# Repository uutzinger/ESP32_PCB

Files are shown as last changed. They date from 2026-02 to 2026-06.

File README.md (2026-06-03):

# ESP32 PCBs

Designed with KiCad by Urs Utzinger, February - June 2026.

- Full size battery operated ESP32-S3-Mini
- Minimial size ESP32-S3.
- Minimal size ESP32-C6, low power.

Based on S3/C6-mini modules.

<table style="width:100%; table-layout:fixed;">
  <tr>
    <td valign="bottom" style="width:33.3%; text-align:center;">
      <a href="./EPS32_S3_1.md">
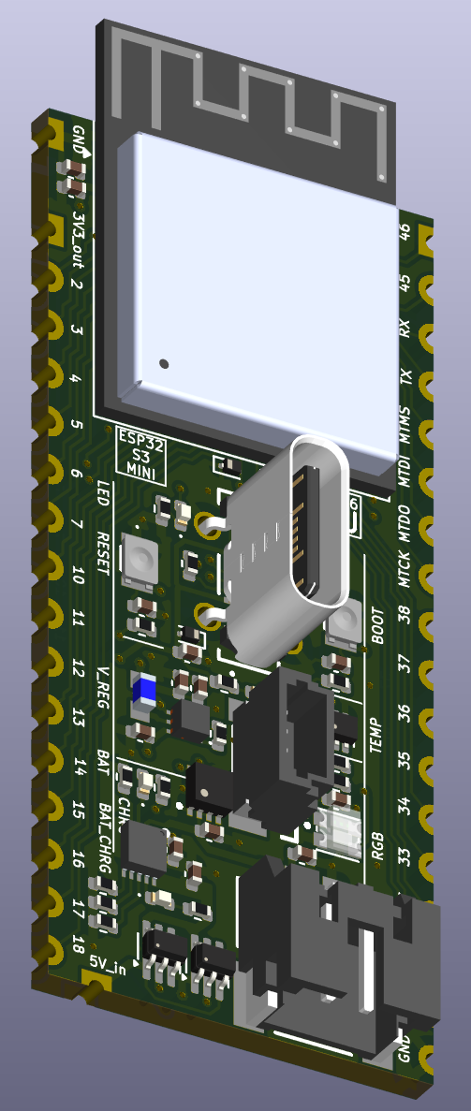
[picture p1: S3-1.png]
ESP32-S3-MINI-1
        
      </a>
      <br>
      <b>ESP32-S3-MINI-1</b>
      <ul style="text-align:left; margin:8px auto; max-width:90%; list-style:none; padding-left:0;">
        <li>📡 Antenna</li>
        <li>🔋 Battery management</li>
        <li>📊 Battery gauge</li>
        <li>⚡ Dual supply power (ext 5V or USB 5V) </li>
        <li>⇄ USB-C</li>
        <li>🔗 QWIIC</li>
        <li>🌈 RGB LED</li>
        <li>🌡 Temperature sensor</li>
        <li>🔘 Bootmode, Reset buttons</li>
      </ul>
    </td>
    <td valign="top" style="width:33.3%; text-align:center;">
      <a href="./EPS32_S3_1U.md">
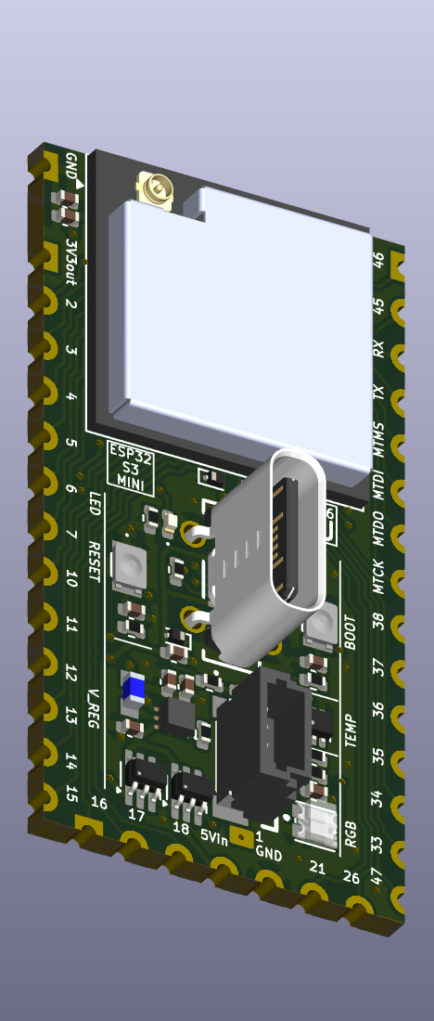
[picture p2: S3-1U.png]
ESP32-S3-MINI-1U
        
      </a>
      <br>
      <b>ESP32-S3-MINI-1U</b>
      <ul style="text-align:left; margin:8px auto; max-width:90%; list-style:none; padding-left:0;">
        <li>⚡ Dual supply power (external 5V or USB 5V)</li>
        <li>⇄ USB-C</li>
        <li>🔗 QWIIC</li>
        <li>🌈 RGB LED</li>
        <li>🌡 Temperature sensor</li>
        <li>🔘 Bootmode, Reset buttons</li>
      </ul>
    </td>
    <td valign="top" style="width:33.3%; text-align:center;">
      <a href="./EPS32_C6_1.md">
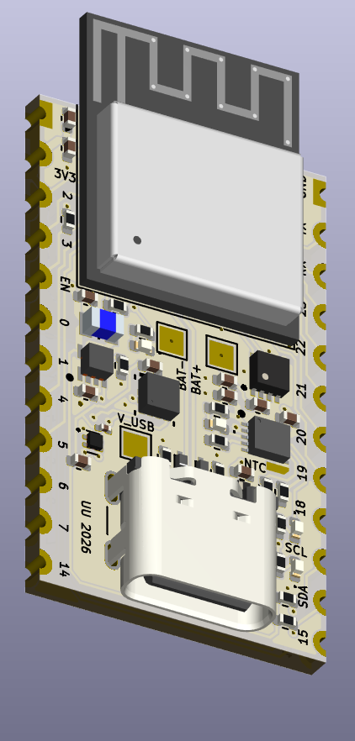
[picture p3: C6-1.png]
ESP32-C6-MINI-1
        
      </a>
      <br>
      <b>ESP32-C6-MINI-1</b>
      <ul style="text-align:left; margin:8px auto; max-width:90%; list-style:none; padding-left:0;">
        <li>📡 Antenna</li>
        <li>🔋 Battery management</li>
        <li>📊 Battery gauge</li>
        <li>⇄ USB-C</li>
        <li>🌡 Temperature sensor</li>
        <li>🫨 Acceleromter</li>
        <li>no Buttons
      </ul>
    </td>
  </tr>
</table>

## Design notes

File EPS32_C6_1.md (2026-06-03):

## ESP32-C6-MINI-1

Size 17.8 x 35.75  mm

- ESP32-C6-MINI-1 module ,main [MCU](ESP32-C6/assets/esp32-c6-mini-1_mini-1u_datasheet_en.pdf) $I_q = 8 \mu A$ 
- BQ25185DLHR [Battery Management / Charger](ESP32-C6/assets/bq25185.pdf) $I_q = 4 \mu A$ (might want to replace with BQ25638 sometime in future)
- TPS62840DLRC 3.3V step-down [Voltage Regulator](ESP32-C6/assets/tps62840.pdf) $I_q = 60nA $
- MAX17048 LiPo [fuel gauge](ESP32-C6/assets/max17048-max17049.pdf) $I_q = 0.5 \mu A$ (would no longer be need if BQ25638 is used)
- TMP110D digital temperature sensor, [TMP110D temperature sensor](ESP32-C6/assets/tmp110.pdf) $I_q = 0.15 \mu A$
- LIS2DW12 [acceleromter](ESP32-C6/assets/lis2dw12.pdf) $I_q = 50 nA$hundred
- USB4105 (USB-C receptacle) (datasheet not added yet) + ESD protection (ESD9B5.0ST5G)
- Castellated edge connectors

### Bill of Materials
- [BOM ESP32 C6 MINI 1](ESP32-C6/BOM.xlsx)

### Design Materials
<table>
  <tr>
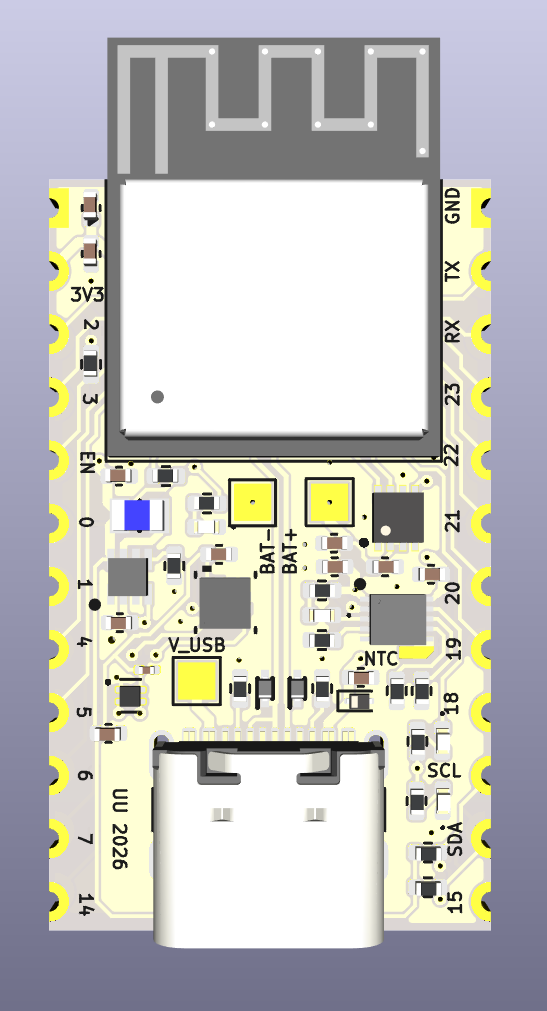
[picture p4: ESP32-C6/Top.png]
Front
    <td></td>
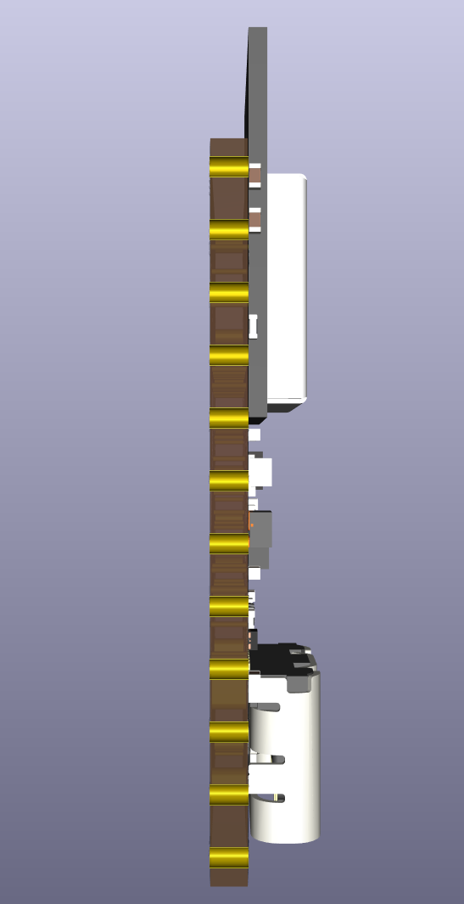
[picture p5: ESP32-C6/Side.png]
    <td></td>
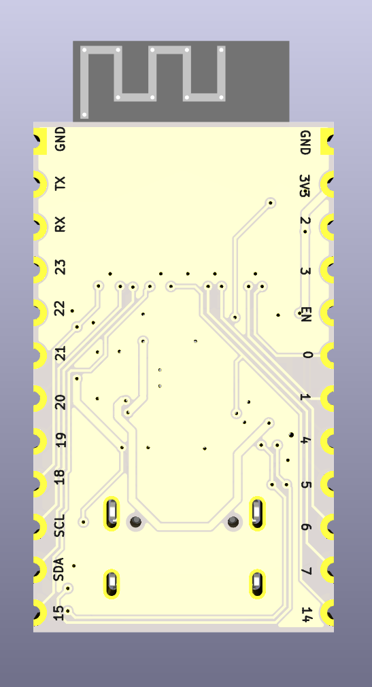
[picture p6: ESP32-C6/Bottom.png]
    <td></td>
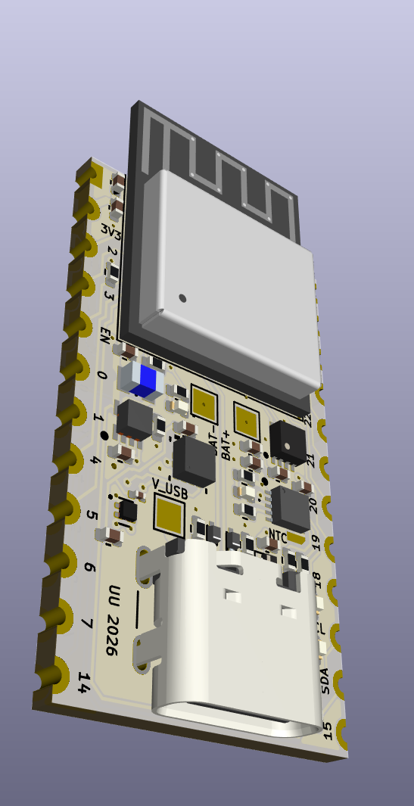
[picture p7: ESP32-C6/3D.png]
    <td></td>    
  </tr>
</table>

<a href="./ESP32-C6/Schematic.svg">
  Schematic
</a>

<a href="./ESP32-C6/PCB.svg">
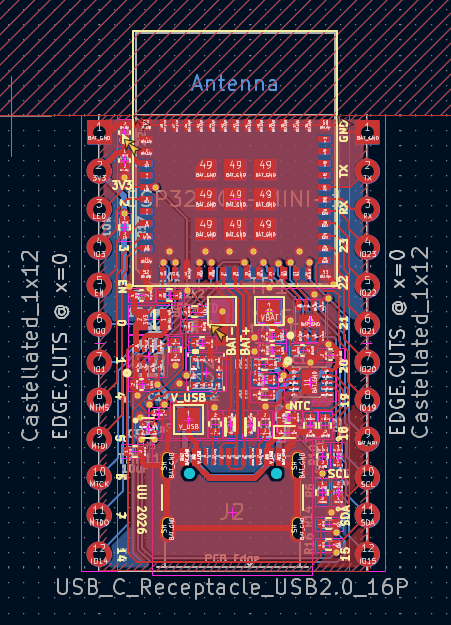
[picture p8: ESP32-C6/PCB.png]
PCB
  
</a>

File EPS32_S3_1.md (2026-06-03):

## ESP32-S3-MINI-1

Size 20.32 x 50.82 mm

- ESP32-S3-MINI-1 module ,main [MCU](ESP32_S3_MINI_1/assets/esp32-s3-mini-1_mini-1u_datasheet_en.pdf)
- BQ25185DLHR [Battery Management / Charger](ESP32_S3_MINI_1/assets/bq25185.pdf)
- TPS6282533DMQR 3.3V step-down [Voltage Regulator](ESP32_S3_MINI_1/assets/tps62825.pdf)
- MAX17048 LiPo [fuel gauge](ESP32_S3_MINI_1/assets/max17048-max17049.pdf)
- TMP102 digital temperature sensor, [TMP102 temperature sensor](ESP32_S3_MINI_1/assets/tmp102.pdf)
- USB4120-03-C (USB-C receptacle)[ESP32_S3_MINI_1/USB4120-03-C USB-C receptacle](ESP32_S3_MINI_1/assets/usb4120-spec.pdf) + ESD protection (ESD9B5.0ST5G)
- WS2812B 2020 RGB LED [WS2812B 2020 RGB LED](ESP32_S3_MINI_1/assets/WS2812B-2020-Worldsemi.pdf), + discrete status LEDs (green/red), 
- Qwiic JST-SH 1.0mm 4-pin connector (I2C), [JST SH 1.0mm (Qwiic)](ESP32_S3_MINI_1/assets/eSH.pdf)
- JST 2.0mm 2-pin LiPo battery connector, [JST PH 2.0mm (LiPo)](ESP32_S3_MINI_1/assets/ePH.pdf)
- Power stage [TFM160808ALC-R47MTAA inductor](ESP32_S3_MINI_1/assets/inductor_commercial_power_tfm160808alc_en.pdf)
- Power switch and reverse polarity protection [LM66100](ESP32_S3_MINI_1/assets/lm66100.pdf)
- Tactile buttons (NANOT160AS) [Buttons](ESP32_S3_MINI_1/assets/nanot.pdf)
- Castellated edge connectors

### Bill of Materials
- [BOM ESP32_S3_MINI_1](ESP32_S3_MINI_1/BOM.xlsx)

### Design Materials
<table>
  <tr>
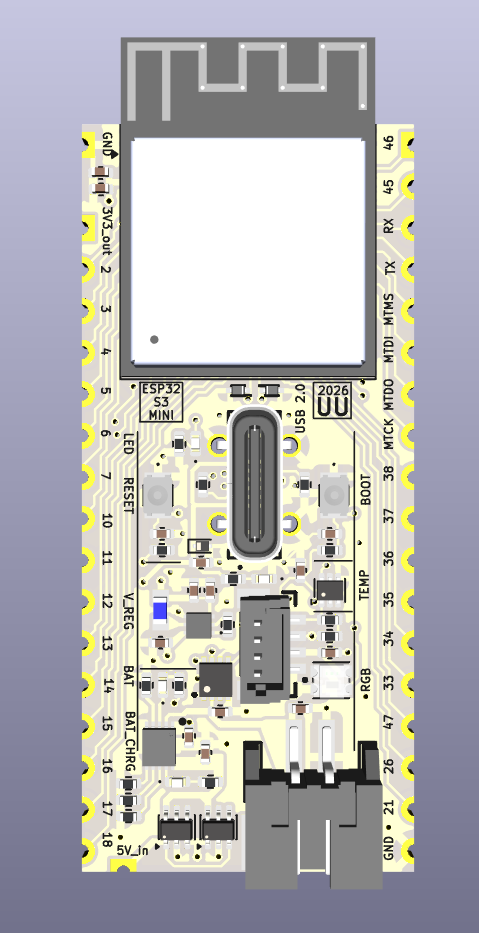
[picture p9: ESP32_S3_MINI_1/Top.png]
Front
    <td></td>
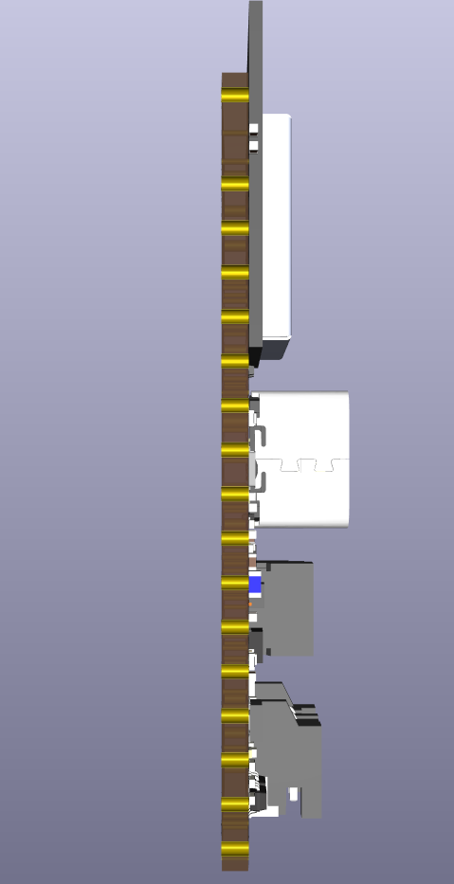
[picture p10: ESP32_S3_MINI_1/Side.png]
    <td></td>
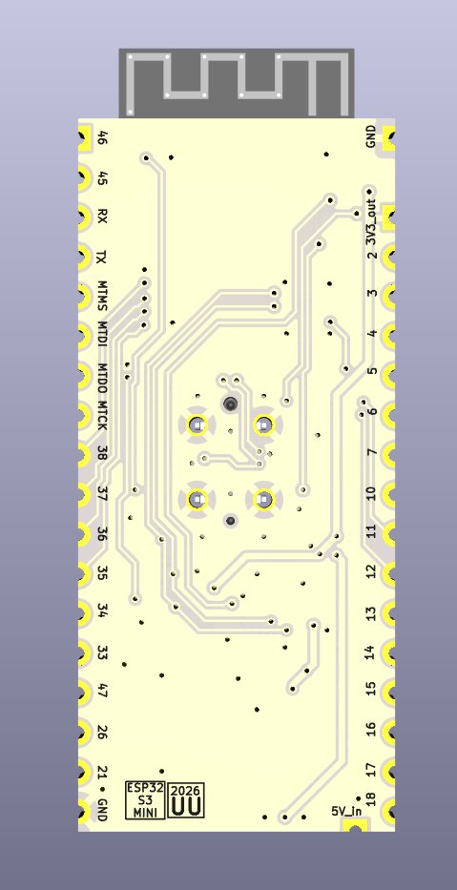
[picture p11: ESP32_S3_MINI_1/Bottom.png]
    <td></td>
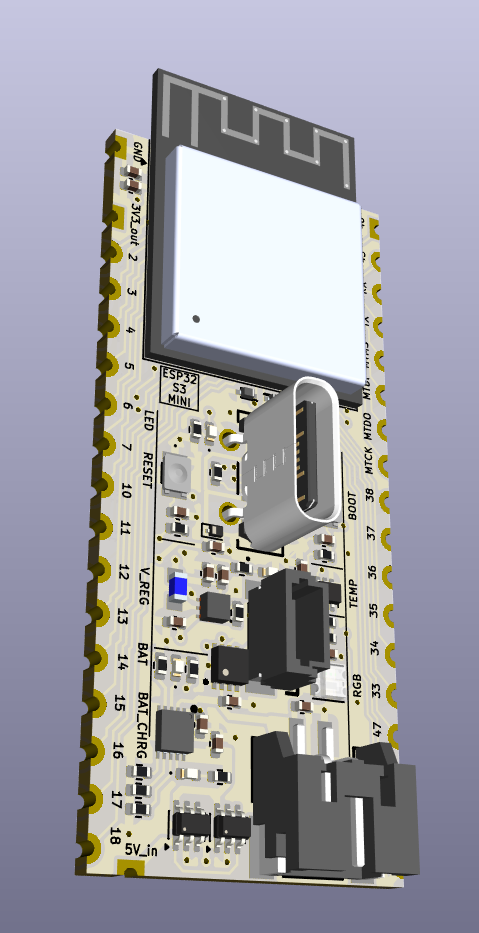
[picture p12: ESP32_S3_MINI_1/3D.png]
    <td></td>    
  </tr>
</table>

<a href="./ESP32_S3_MINI_1/Schematic.svg">
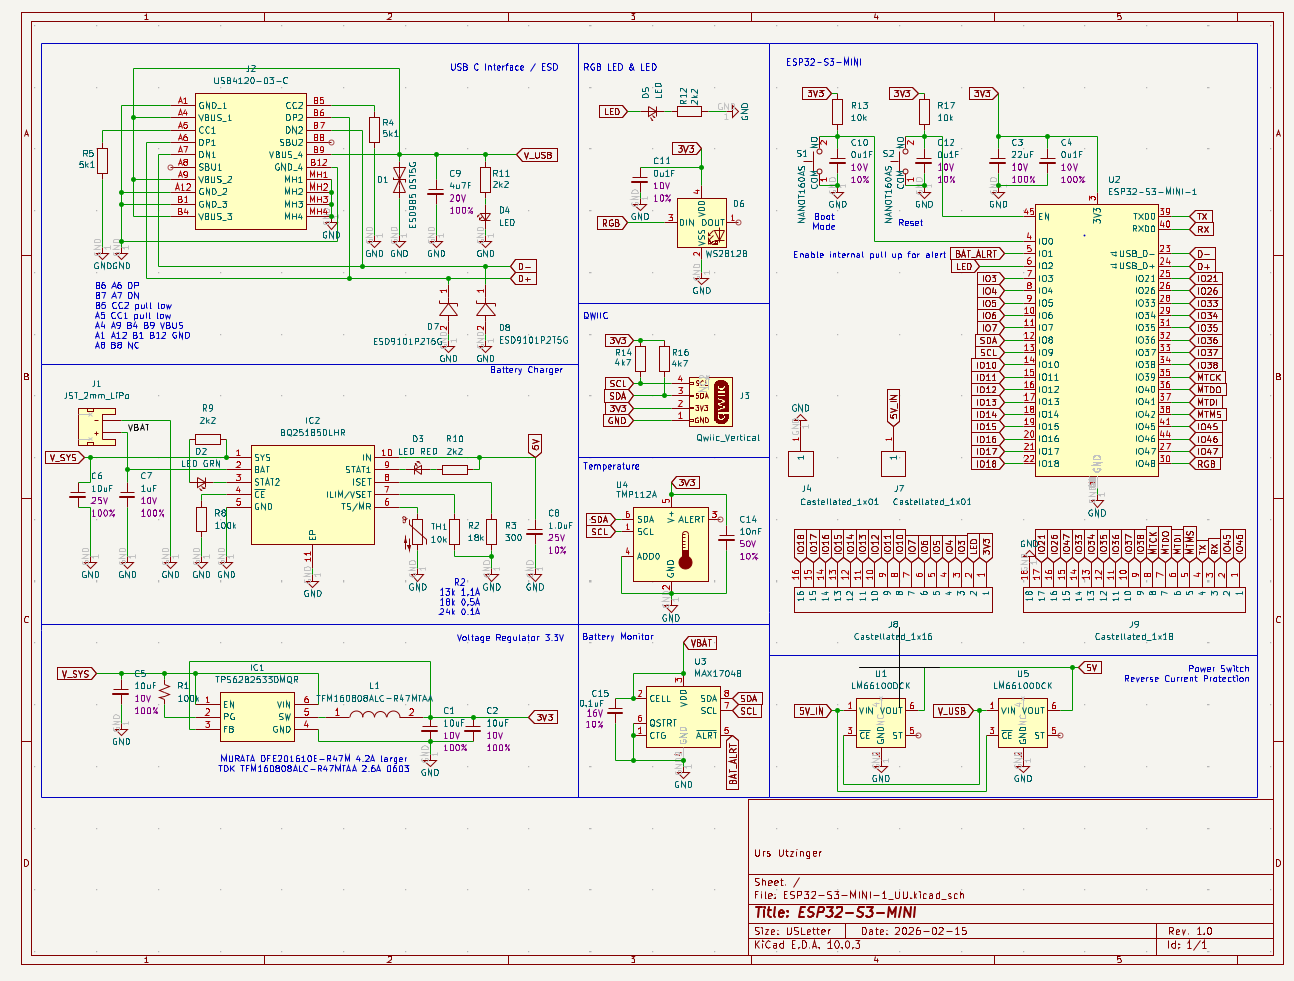
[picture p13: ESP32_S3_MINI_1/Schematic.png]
Schematic
  
</a>

<a href="./ESP32_S3_MINI_1/PCB.svg">
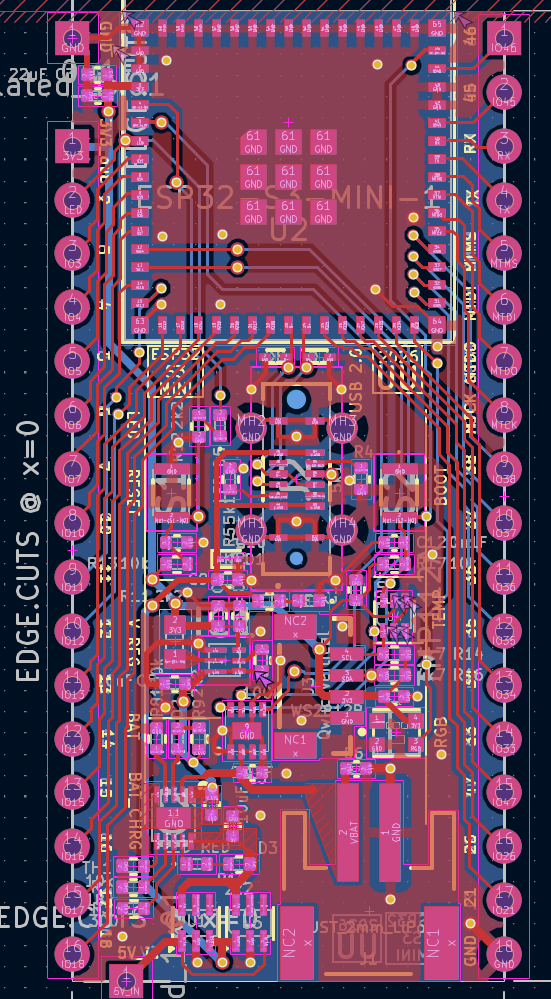
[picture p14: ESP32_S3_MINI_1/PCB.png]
PCB
  
</a>

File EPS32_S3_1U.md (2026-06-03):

## ESP32-S3-MINI-1U

Size 20.32 x 38.1 mm

- ESP32-S3-MINI-1U module ,main [MCU](ESP32_S3_MINI_1U/assets/esp32-s3-mini-1_mini-1u_datasheet_en.pdf)
- TPS6282533DMQR 3.3V step-down [Voltage Regulator](ESP32_S3_MINI_1U/assets/tps62825.pdf)
- TMP112 digital temperature sensor, [TMP112 temperature sensor](ESP32_S3_MINI_1U/assets/tmp112.pdf)
- USB4120-03-C (USB-C receptacle)[ESP32_S3_MINI_1/USB4120-03-C USB-C receptacle](ESP32_S3_MINI_1U/assets/usb4120-spec.pdf) + ESD protection (ESD9B5.0ST5G)
- WS2812B 2020 RGB LED [WS2812B 2020 RGB LED](ESP32_S3_MINI_1U/assets/WS2812B-2020-Worldsemi.pdf), + discrete status LEDs (green/red), 
- Qwiic JST-SH 1.0mm 4-pin connector (I2C), [JST SH 1.0mm (Qwiic)](ESP32_S3_MINI_1U/assets/eSH.pdf)
- Power stage [TFM160808ALC-R47MTAA inductor](ESP32_S3_MINI_1U/assets/inductor_commercial_power_tfm160808alc_en.pdf)
- Tactile buttons (NANOT160AS) [Buttons](ESP32_S3_MINI_1U/assets/nanot.pdf)
- Power switch and reverse polarity protection [LM66100](ESP32_S3_MINI_1U/assets/lm66100.pdf)
- Castellated edge connectors

### Bill of Materials
- [BOM ESP32_S3_MINI_1U](ESP32_S3_MINI_1U/BOM.xlsx)

### Design Materials
<table>
  <tr>
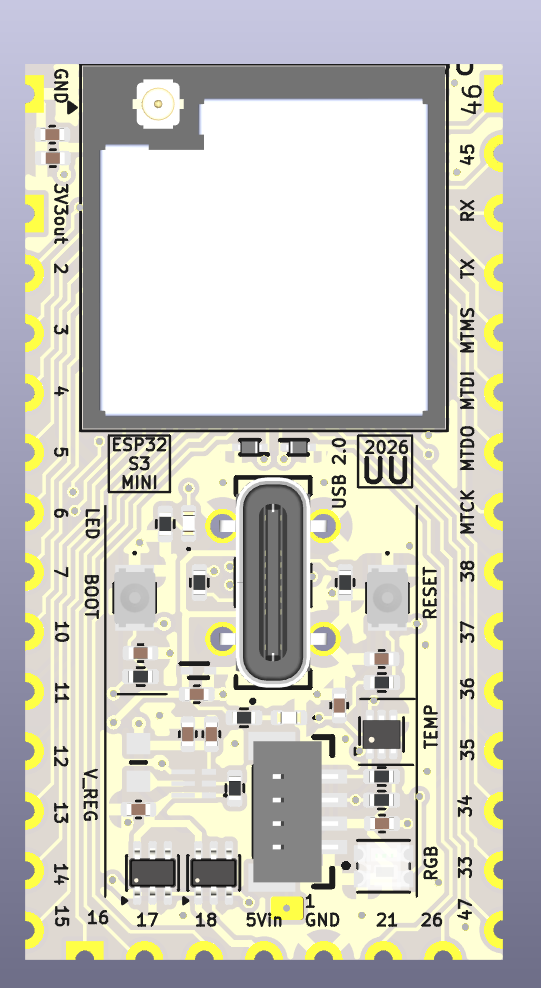
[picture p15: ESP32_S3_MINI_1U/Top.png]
Front
    <td></td>
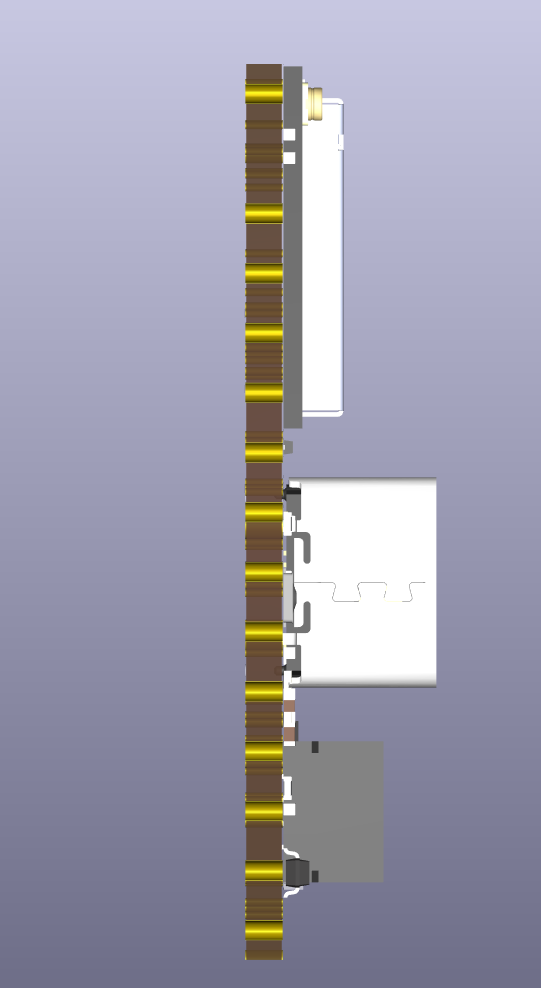
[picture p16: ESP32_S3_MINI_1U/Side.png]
    <td></td>
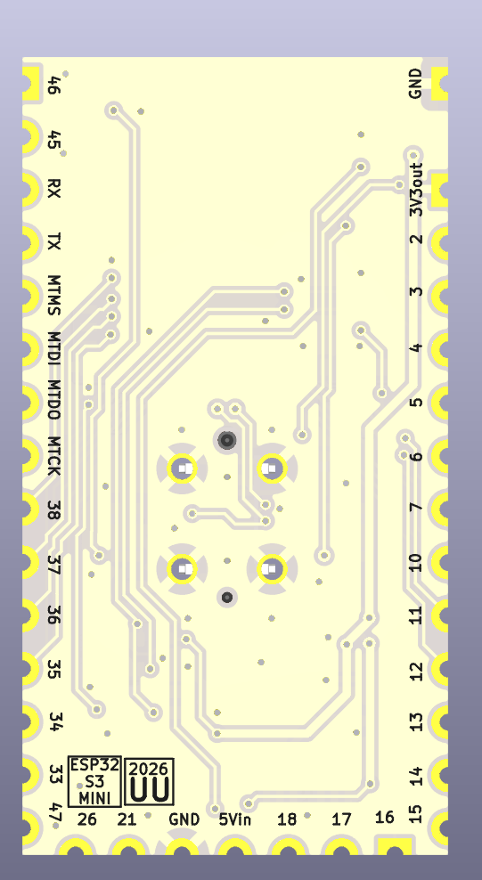
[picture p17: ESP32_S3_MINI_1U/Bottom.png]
    <td></td>
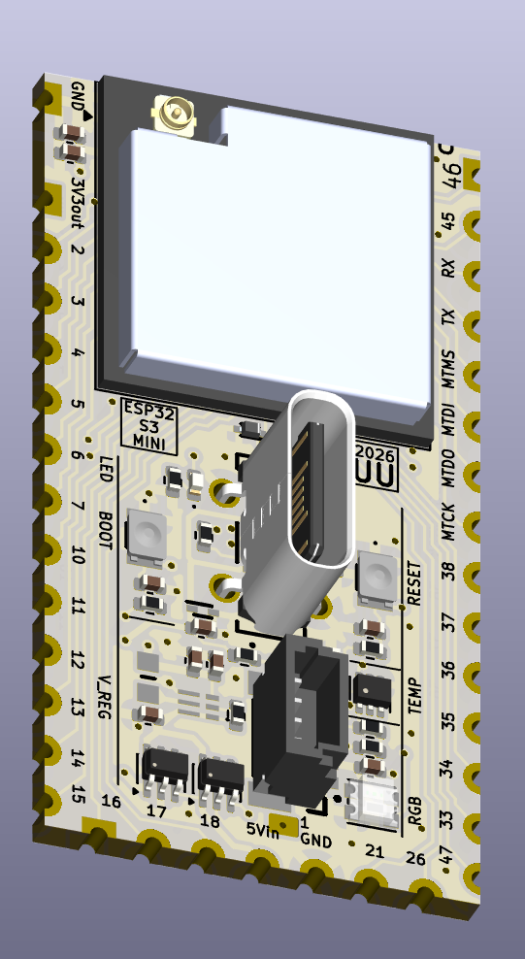
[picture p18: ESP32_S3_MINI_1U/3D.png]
    <td></td>    
  </tr>
</table>

<a href="./ESP32_S3_MINI_1U/ESP32-S3-MINI-1U_UU.svg">
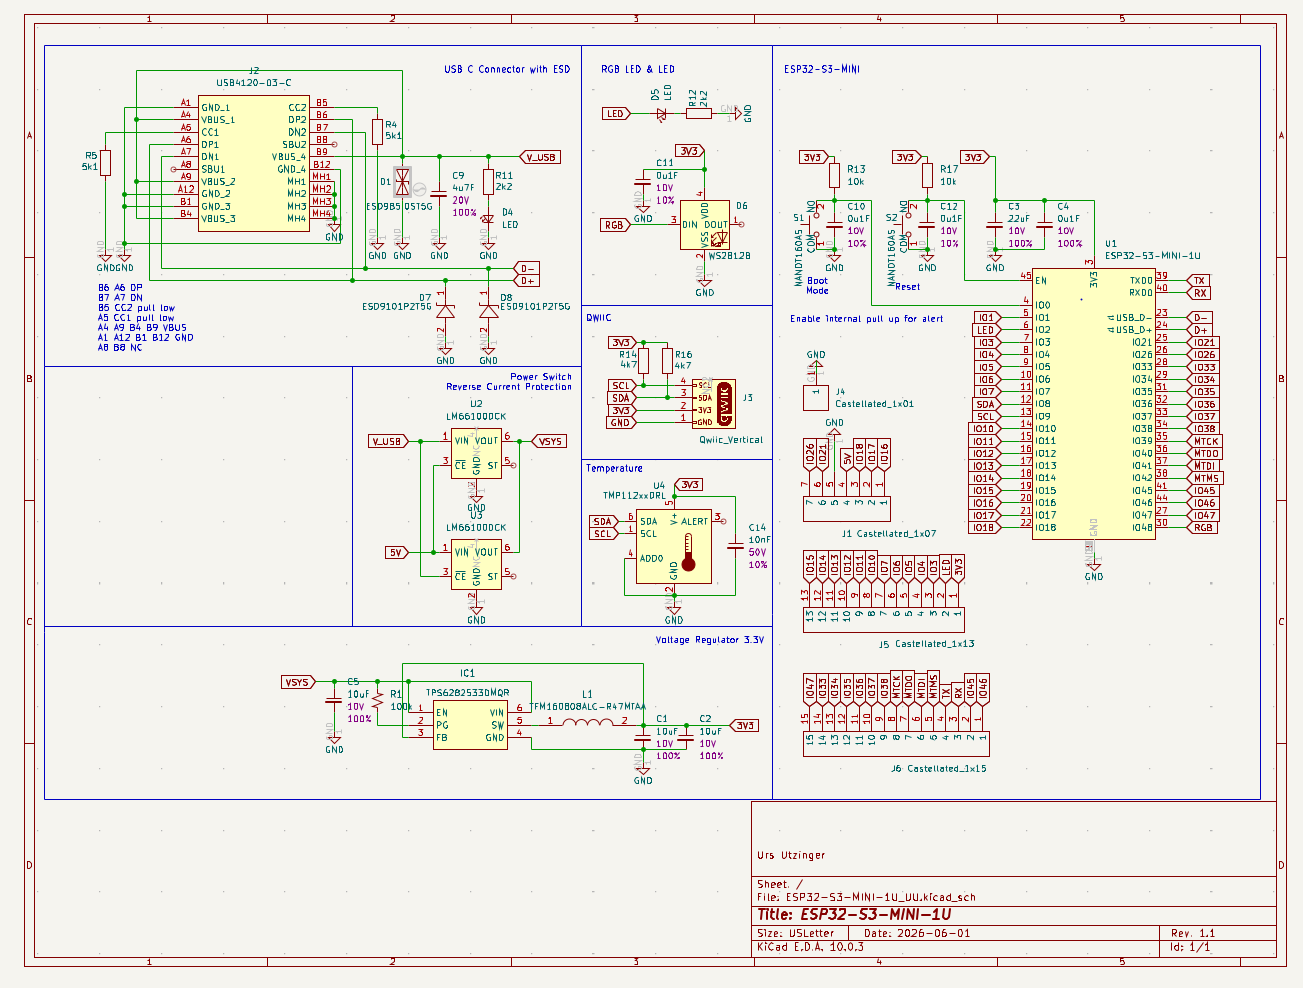
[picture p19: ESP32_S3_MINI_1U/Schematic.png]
Schematic
  
</a>

<a href="./ESP32_S3_MINI_1U/PCB.svg">
  PCB
</a>

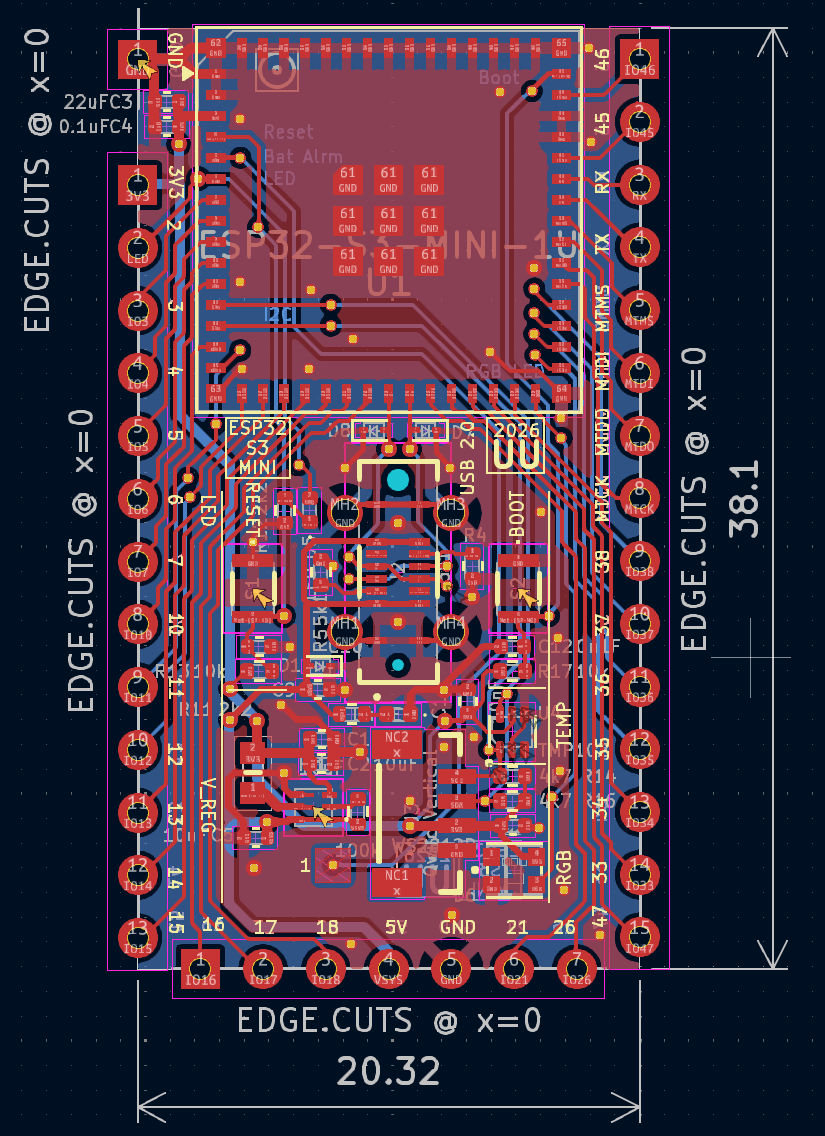
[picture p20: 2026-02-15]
ESP32_S3_MINI_1U/PCB.png

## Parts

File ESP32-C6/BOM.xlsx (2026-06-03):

Item # | *Designator | *Package/Footprint | *Qty | Item | Manufacturer | *Mfg Part # | Description / Value | Part # LCSC | LCSC Weblink | LSCS $ | Cost LCSC | Part # Mouser | Mouser Weblink | Mouser $
 | C1,C2 | C_0402_1005Metric | 2 | Capacitor | muRata | GRM155R61A475KEAAD | 4u7F | C77004 | https://www.lcsc.com/product-detail/C77004.html?s_z=n_C77004 | 0.81 | 1.62
 | C14 | C_0201_0603Metric | 1 | Capacitor | muRata | GRM033R71E103KE14D (https://www.lcsc.com/product-detail/C85930.html) | 10nF | C85930 (https://www.lcsc.com/product-detail/C85930.html) | https://www.lcsc.com/product-detail/C85930.html | 0.22 | 0.22
 | C10,C15,C4 | C_0402_1005Metric | 2 | Capacitor | muRata | GRM155R71H104KE14 (https://www.lcsc.com/product-detail/C77020.html) | 0u1F | C77020 (https://www.lcsc.com/product-detail/C77020.html) | https://www.lcsc.com/product-detail/C77020.htm | 0.33 | 0.66
 | C3 | C_0402_1005Metric | 1 | Capacitor | muRata | GRM158R61A226ME15D | 22uF | C3845593 | https://www.lcsc.com/product-detail/C3845593.html?s_z=n_C3845593 | 0.57 | 0.57
 | C6,C5, C9 | C_0402_1005Metric | 3 | Capacitor | muRata | GRM155R61A106ME44D | 10uF | C77000 | https://www.lcsc.com/product-detail/C77000.html?s_z=n_C77000 | 0.58 | 1.74
 | C7,C8 | C_0402_1005Metric | 2 | Capacitor | muRata | GRM155R61E105KA12 (https://www.lcsc.com/product-detail/C77009.html) | 1uF | C77009 (https://www.lcsc.com/product-detail/C77009.html) | https://www.lcsc.com/product-detail/C77009.html | 0.69 | 1.38
 | D1 | D_SOD-923 | 1 | ESD9B5.0ST5G | onSemi | ESD9B5.0ST5G | ESD9B5.0ST5G | C111566 | https://www.lcsc.com/product-detail/C111566.html?s_z=n_C111566 | 0.04 | 0.04
 | D2 | LED_0402_1005Metric | 1 | LED GRN | TOGIALED | TJ-S1005CL4T5ALC2G-A5 (https://www.lcsc.com/product-detail/C917188.html) | LED GREEN | C917188 (https://www.lcsc.com/product-detail/C917188.html) | https://www.lcsc.com/product-detail/C917188.html | 0.66
 | D3 | LED_0402_1005Metric | 1 | LED RED | TOGIALED | TJ-S1005SW4TGLC2R-A5 (https://www.lcsc.com/product-detail/C273598.html) | LED RED | C273598 (https://www.lcsc.com/product-detail/C273598.html) | https://www.lcsc.com/product-detail/C273598.html | 0.41 | 0.41
 | D7 | LED_0402_1005Metric | 1 | LED WHITE | TOGIALED | TJ-S1005CL4T5ALC3D (https://www.lcsc.com/product-detail/C917191.html) | LED WHITE | C917191 (https://www.lcsc.com/product-detail/C917191.html) | https://www.lcsc.com/product-detail/C917191.html | 0.48
 | D5 | LED_0402_1005Metric | 1 | LED BLUE | Vishay | VLMB1500-GS08 | LED BLUE | C511042 | https://www.lcsc.com/product-detail/C511042.html?s_z=n_C511042 | 0.2
 | D8,D9 | D_SOD-923 | 2 | ESD9101P2T5G | onSemi | ESD9101P2T5G | ESD9101P2T5G | C41348159 | https://www.lcsc.com/product-detail/C41348159.html?s_z=n_ESD9101P2T5G | 0.56
 | IC1 | SON50P150X200X100-8N-D | 1 | TPS62840DLCR
 | IC2 | SON40P220X200X80-11N | 1 | BQ25185DLHR
 | J1,J4 | Castellated_1x12_P2.54mm_D0.80mm | 2 | Castellated_1x12
 | J2 |  | 1 | USB_C_Receptacle_USB2.0_16P |  | USB_C_Receptacle_GCT_USB4105-xx-A_16P_TopMnt_Horizontal
 | L1 | DFE201210S1R0MP2 | 1 | Inductor |  | DFE201210S-2R2M=P2
 | R1 | R_0402_1005Metric | 1 | 267K
 | R14,R16 | R_0402_1005Metric | 2 | 4k7
 | R17,R13 | R_0402_1005Metric | 2 | 10k
 | R2 | R_0402_1005Metric | 1 | 18k
 | R3 | R_0402_1005Metric | 1 | 300
 | R5,R4 | R_0402_1005Metric | 2 | 5k1
 | R7,R10,R6,R9 | R_0402_1005Metric | 4 | 2k2
 | R8 | R_0402_1005Metric | 1 | 100k
28 | TP1 | TestPoint_Pad_1.5x1.5mm | 1 | TestPoint
29 | TP3 | TestPoint_Pad_1.5x1.5mm | 1 | TestPoint
 | U1 | ESP32-C6-MINI-1 | 1 | MCU Module | Espressif Systems
 | U2 | LGA-12_2X2X0P7_STM | 1 | LIS2DW12TR
 | U3 | DFN-8_2x2mm_P0.5mm_EP1.2x0.8mm | 1 | MAX17048
 | U5 | Texas_X2SON-5_0.8x0.8mm_P0.48mm | 1 | TMP110D

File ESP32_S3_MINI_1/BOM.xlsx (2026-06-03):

Id | Designator | Footprint | Quantity | Item | Manufacturer | Mfg Part # | Description/Value | Part # LCSC | LCSC | Cost LCSC |  | Part # Mouser | Mouser website | Cost Mouser
1 | C11,C12,C10,C15,C4 | C_0402_1005Metric | 5 | Capacitor | muRata | GRM155R71A104KA01D | 0u1F | C71687 | https://www.lcsc.com/product-detail/C71687.html?s_z=n_C71687 | 0.32 | 1.6
2 | C14 | C_0402_1005Metric | 1 | Capacitor | YAGEO | CC0402KRX7R6BB103 | 10nF | C541371 | https://www.lcsc.com/product-detail/C541371.html?s_z=n_C541371 | 0.13 | 0.13
3 | C3 | C_0402_1005Metric | 1 | Capacitor | muRata | GRM158R61A226ME15D | 22uF | C3845593 | https://www.lcsc.com/product-detail/C3845593.html?s_z=n_C3845593 | 0.57 | 0.57
4 | C5,C1,C2,C6 | C_0402_1005Metric | 4 | Capacitor | muRata | GRM155R61A106ME44D | 10uF | C77000 | https://www.lcsc.com/product-detail/C77000.html?s_z=n_C77000 | 0.58 | 2.32
5 | C7,C8 | C_0402_1005Metric | 2 | Capacitor | muRata | GCM155C71A105KE38D | 1uF | C126521 | https://www.lcsc.com/product-detail/C126521.html?s_z=n_C126521 | 0.96 | 1.92
6 | C9 | C_0402_1005Metric | 1 | Capacitor | muRata | GRM155R61A475KEAAD | 4u7F | C77004 | https://www.lcsc.com/product-detail/C77004.html?s_z=n_C77004 | 0.81 | 0.81
7 | D1 | D_SOD-923 | 1 | V_USB ESD | onSemi | ESD9B5.0ST5G | ESD9B5.0ST5G | C111566 | https://www.lcsc.com/product-detail/C111566.html?s_z=n_C111566 | 0.04 | 0.04 | 863-ESD9B5.0ST5G | https://www.mouser.com/ProductDetail/onsemi/ESD9B5.0ST5G?qs=HL4IEvuNMQqfrGPZiLZXfQ%3D%3D | 0.1
8 | D2 | LED_0402_1005Metric | 1 | LED | Vishay | VLMG1500-GS08 | LED GRN | C511404 | https://www.lcsc.com/product-detail/C511404.html?s_z=n_C511404 | 0.19 | 0.19 | 78-VLMG1500-GS08 | https://www.mouser.com/ProductDetail/Vishay-Semiconductors/VLMG1500-GS08 | 0.34
9 | D3 | LED_0402_1005Metric | 1 | LED | Vishay | VLMS1500-GS08 | LED RED | C511370 | https://www.lcsc.com/product-detail/C511370.html?s_z=n_C511370 | 0.17 | 0.17 | 78-VLMS1500-GS08 | https://www.mouser.com/ProductDetail/Vishay-Semiconductors/VLMS1500-GS08 | 0.24
10 | D4,D5 | LED_0402_1005Metric | 2 | LED | Vishay | VLMB1500-GS08 | LED BLUE | C511042 | https://www.lcsc.com/product-detail/C511042.html?s_z=n_C511042 | 0.2 | 0.4 | 78-VLMB1500-GS08 | https://www.mouser.com/ProductDetail/Vishay-Semiconductors/VLMB1500-GS08 | 0.27
11 | D6 | WS2812_2020 | 1 | RGB LED | Worldsemi | WS2812B-2020 | WS2812B | C965555 | https://www.lcsc.com/product-detail/C965555.html?s_z=n_C965555 | 0.45 | 0.45
12 | D7,D8 | D_SOD-923 | 2 | USB ESD | Onsemi | ESD9101P2T5G | ESD9101P2T5G | C41348159 | https://www.lcsc.com/product-detail/C41348159.html?s_z=n_ESD9101P2T5G | 0.56 | 1.12 | 863-ESD9101P2T5G | https://www.mouser.com/ProductDetail/onsemi/ESD9101P2T5G?qs=5aG0NVq1C4ySlMx2D5w2xw%3D%3D | 0.26
13 | IC1 | TPS6282533DMQR | 1 | Volt Regulator | TI | TPS6282533DMQR | TPS6282533DMQR | C3189971 | https://www.lcsc.com/product-detail/C3189971.html?s_z=n_C3189971 | 1.17 | 1.17 | 595-TPS6282533DMQR | https://www.mouser.com/ProductDetail/Texas-Instruments/TPS6282533DMQR?qs=e8oIoAS2J1TctVdod4W0lA%3D%3D | 1.25
14 | IC2 | SON40P220X200X80-11N | 1 | Bat Charger | TI | BQ25185DLHR | BQ25185DLHR | C19725033 | https://www.lcsc.com/product-detail/C19725033.html?s_z=n_C19725033 | 1.9 | 1.9 | 595-BQ25185DLHR | https://www.mouser.com/ProductDetail/Texas-Instruments/BQ25185DLHR?qs=Z%252BL2brAPG1IbO%2FV3RqsaPw%3D%3D | 2.03
15 | J1 | JST_1x02_P2.0mm_Horizontal_SMD | 1 | Connector | JST | JST S2B-PH-SM4-TB | JST_2mm_LiPo, SMF, right angle | C295747 | https://www.lcsc.com/product-detail/C295747.html?s_z=n_C295747 | 0.2 | 0.2 | 306-S2BPHSM4TBLFSN | https://www.mouser.com/ProductDetail/JST-Commercial/S2B-PH-SM4-TBLFSN?qs=QpmGXVUTftGPIOdg%2F2bstg%3D%3D | 0.49
16 | J2 | USB412003C | 1 | Connector | GCT | USB4120-03-C | USB4120-03-C | C3445864 | https://www.lcsc.com/product-detail/C3445864.html?s_z=n_C3445864 | 1.31 | 1.31 | 640-USB4120-03-C | https://www.mouser.com/ProductDetail/GCT/USB4120-03-C?qs=KUoIvG%2F9IlZaAd13sVDhkQ%3D%3D | 0.86
17 | J3 | JST_1x04_P1.0mm_Vertical_SMD | 1 | Connector | BOOMELE | 1.0T-4PLTPZ | Qwiic_Vertical | C2974722 | https://www.lcsc.com/product-detail/C2974722.html | 0.65 | 0.65
18 | J7,J4 | Castellated_1x01_P2.54mm_D0.80mm | 1 | Connector | D.N.P. | D.N.P. | Castellated_1x01 |  | Do No Populate
19 | J8 | Castellated_1x16_P2.54mm_D0.80mm | 1 | Connector | D.N.P. | D.N.P. | Castellated_1x16 |  | Do No Populate
20 | J9 | Castellated_1x18_P2.54mm_D0.80mm | 1 | Connector | D.N.P. | D.N.P. | Castellated_1x18 |  | Do No Populate
21 | L1 | C_0603 | 1 | Inductor | TDK | TFM160808ALC-R47MTAA | TFM160808ALC-R47MTAA | C695609 | https://www.lcsc.com/product-detail/C695609.html?s_z=n_C695609 | 0.13 | 0.13 | 810-TFM160808ALCR47A | https://www.mouser.com/ProductDetail/TDK/TFM160808ALC-R47MTAA?qs=3SnDZBG9J%252B6tokb499UWsQ%3D%3D | 0.25
22 | R1,R8 | R_0402_1005Metric | 2 | Resistor | YAGEO | RC0402FR-07100KL | 100k | C60491 | https://www.lcsc.com/product-detail/C60491.html?s_z=n_C60491 | 0.08 | 0.16
23 | R14,R16 | R_0402_1005Metric | 2 | Resistor | YAGEO | RC0402FR-074K7L | 4k7 | C105871 | https://www.lcsc.com/product-detail/C105871.html?s_z=n_C105871 | 0.08 | 0.16
24 | R15 | R_0402_1005Metric | 1 | Resistor | YAGEO | RC0402FR-07330RL | 330 | C105875 | https://www.lcsc.com/product-detail/C105875.html?s_z=n_C105875 | 0.08 | 0.08
25 | R2 | R_0402_1005Metric | 1 | Resistor | YAGEO | RC0402FR-0718KL | 18k | C138044 | https://www.lcsc.com/product-detail/C138044.html?s_z=n_C138044 | 0.08 | 0.08
26 | R3 | R_0402_1005Metric | 1 | Resistor | YAGEO | RC0402FR-07300RL | 300 | C138010 | https://www.lcsc.com/product-detail/C138010.html?s_z=n_C138010 | 0.08 | 0.08
27 | R4,R5 | R_0402_1005Metric | 2 | Resistor | YAGEO | RC0402FR-075K1L | 5k1 | C105872 | https://www.lcsc.com/product-detail/C105872.html?s_z=n_C105872 | 0.08 | 0.16
28 | R9,R12,R10,R11 | R_0402_1005Metric | 4 | Resistor | YAGEO | RC0402FR-072K2L | 2k2 | C114762 | https://www.lcsc.com/product-detail/C114762.html?s_z=n_C114762 | 0.09 | 0.36
29 | S1,S2 | NANOT160AS | 2 | Micro Switch | C&K | NANOT160AS | NANOT160AS | C2760981 | https://www.lcsc.com/product-detail/C2760981.html?s_z=n_C2760981 | 1.72 | 3.44 | 611-NANOT160AS | https://www.mouser.com/ProductDetail/CK/NANOT160AS?qs=OlC7AqGiEDnK60t%2FC6IJyA%3D%3D | 0.4
30 | R13,R17 | R_0402_1005Metric | 2 | Resistor | YAGEO | RC0402FR-0710KL | 10k | C60490 | https://www.lcsc.com/product-detail/C60490.html?s_z=n_C60490 | 0.08 | 0.16
31 | TH1 | R_0402_1005Metric | 1 | Thermistor | MURATA | NCP15XH103F03RC | 10k NTC | C77131 | https://www.lcsc.com/product-detail/C77131.html?s_z=n_C77131 | 0.01 | 0.01
32 | U2 | ESP32-S2-MINI-1 SMD | 1 | MCU Module | Espressif | ESP32-S3-MINI-1-N8 | ESP32 S3 Mini 1 8MB Flash | C2913206 | https://www.lcsc.com/product-detail/C2913206.html?s_z=n_C2913206 | 4.6185 | 4.6185
33 | U3 | DFN-8_2x2mm_P0.5mm_EP1.2x0.8mm | 1 | Bat Gauge | Maxim | MAXIM MAX17048G+T10 | MAX17048 | C2682616 | https://www.lcsc.com/product-detail/C2682616.html?s_z=n_C2682616 | 2.66 | 2.66 | 700-MAX17048G+T10 | https://www.mouser.com/ProductDetail/Analog-Devices-Maxim-Integrated/MAX17048G%2bT10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 | 5.77
34 | U4 | SOT-563 | 1 | Temp Sensor | Texas Instruments | TMP102AIDRLR | TMP102 | C99269 | https://www.lcsc.com/product-detail/C99269.html?s_z=n_C99269 | 0.22 | 0.22 | 595-TMP102AQDRLRQ1 | https://www.mouser.com/ProductDetail/Texas-Instruments/TMP102AQDRLRQ1?qs=asCBFxFfL1SM%2FKfsYcTt1w%3D%3D | 1.52
35 | U5,U1 | SOT-363_SC-70-6 | 2 | Ideal Diode | Texas Instruments | LM66100DCK | Ideal Diode, Input Polarity Prot. | C2869734 | https://www.lcsc.com/product-detail/C2869734.html?s_z=n_C2869734 | 0.88 | 1.76 | 595-LM66100DCKT | https://www.mouser.com/ProductDetail/Texas-Instruments/LM66100DCKT?qs=vLWxofP3U2zoiBCtDTudjw%3D%3D | 0.85
 |  |  |  |  |  |  |  |  |  |  | 29.0285

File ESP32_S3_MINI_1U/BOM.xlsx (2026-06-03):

PCBWay BoM
Item # | *Designator | *Qty | Manufacturer | *Mfg Part # | Description / Value | Vendor Part # | *Package/Footprint | Category | Your Instructions / Notes | *Unit Price(5 sets) | *Total | *Delivery Time | *Actual Purchase Mfg Part # | *PCBWay Note | Customer Reply
1 | C11,C12,C10,C4 | 4 | muRata | GRM155R71A104KA01D | 0u1F | C71687 | C_0402_1005Metric | Capacitor | https://www.lcsc.com/product-detail/C71687.html?s_z=n_C71687 | $0.063 | $1.260
2 | C14 | 1 | YAGEO | CC0402KRX7R6BB103 | 10nF | C541371 | C_0402_1005Metric | Capacitor | https://www.lcsc.com/product-detail/C541371.html?s_z=n_C541371 | $0.126 | $0.630
3 | C3 | 1 | muRata | GRM158R61A226ME15D | 22uF | C3845593 | C_0402_1005Metric | Capacitor | https://www.lcsc.com/product-detail/C3845593.html?s_z=n_C3845593 | $0.263 | $1.315
4 | C5,C1,C2 | 3 | muRata | GRM155R61A106ME44D | 10uF | C77000 | C_0402_1005Metric | Capacitor | https://www.lcsc.com/product-detail/C77000.html?s_z=n_C77000 | $0.123 | $1.845
5 | C9 | 1 | muRata | GRM155R61A475KEAAD | 4u7F | C77004 | C_0402_1005Metric | Capacitor | https://www.lcsc.com/product-detail/C77004.html?s_z=n_C77004 | $0.158 | $0.790
6 | D1 | 1 | onSemi | ESD9B5.0ST5G | ESD9B5.0ST5G | C111566『 』863-ESD9B5.0ST5G | D_SOD-923 | V_USB ESD | https://www.lcsc.com/product-detail/C111566.html?s_z=n_C111566『 』https://www.mouser.com/ProductDetail/onsemi/ESD9B5.0ST5G?qs=HL4IEvuNMQqfrGPZiLZXfQ%3D%3D | $0.212 | $1.060
7 | D4,D5 | 2 | Vishay | VLMB1500-GS08 | LED BLUE | C511042『 』78-VLMB1500-GS08 | LED_0402_1005Metric | LED | https://www.lcsc.com/product-detail/C511042.html?s_z=n_C511042『 』https://www.mouser.com/ProductDetail/Vishay-Semiconductors/VLMB1500-GS08 | $0.419 | $4.190
8 | D6 | 1 | Worldsemi | WS2812B-2020 | WS2812B | C965555 | WS2812_2020 | RGB LED | https://www.lcsc.com/product-detail/C965555.html?s_z=n_C965555 | $0.119 | $0.595
9 | D7,D8 | 2 | onSemi | ESD9101P2T5G | ESD9101P2T5G | C41348159『 』863-ESD9101P2T5G | D_SOD-923 | USB ESD | https://www.lcsc.com/product-detail/C41348159.html?s_z=n_ESD9101P2T5G『 』https://www.mouser.com/ProductDetail/onsemi/ESD9101P2T5G?qs=5aG0NVq1C4ySlMx2D5w2xw%3D%3D | $0.066 | $0.660
10 | IC1 | 1 | Texas Instruments | TPS6282533DMQR | TPS6282533DMQR | C3189971『 』595-TPS6282533DMQR | TPS6282533DMQR | Volt Regulator | https://www.lcsc.com/product-detail/C3189971.html?s_z=n_C3189971『 』https://www.mouser.com/ProductDetail/Texas-Instruments/TPS6282533DMQR?qs=e8oIoAS2J1TctVdod4W0lA%3D%3D | $1.811 | $9.055
11 | J1 | 1 | Do No Populate | Do No Populate | Castellated_1x07 |  | Castellated_1x07_P2.54mm_D0.80mm | Connector |  |  |  |  |  | [DNP不要贴];
12 | J2 | 1 | GCT | USB4120-03-C | USB4120-03-C | C3445864『 』640-USB4120-03-C | USB412003C | Connector | https://www.lcsc.com/product-detail/C3445864.html?s_z=n_C3445864『 』https://www.mouser.com/ProductDetail/GCT/USB4120-03-C?qs=KUoIvG%2F9IlZaAd13sVDhkQ%3D%3D | $1.642 | $8.210
13 | J3 | 1 | BOOMELE | 1.0T-4P | Qwiic_Vertical | C2974722 | JST_1x04_P1.0mm_Vertical_SMD | Connector | https://www.lcsc.com/product-detail/C2974722.html | $0.430 | $2.150 |  | 1.0T-4P卧贴编带
14 | J4 | 1 | Do No Populate | Do No Populate | Castellated_1x01 |  | Castellated_1x01_P2.54mm_D0.80mm | Connector |  |  |  |  |  | [DNP不要贴];
15 | J5 | 1 | Do No Populate | Do No Populate | Castellated_1x13 |  | Castellated_1x13_P2.54mm_D0.80mm | Connector |  |  |  |  |  | [DNP不要贴];
16 | J6 | 1 | Do No Populate | Do No Populate | Castellated_1x15 |  | Castellated_1x15_P2.54mm_D0.80mm | Connector |  |  |  |  |  | [DNP不要贴];
17 | L1 | 1 | TDK | TFM160808ALC-R47MTAA | TFM160808ALC-R47MTAA | C695609『 』810-TFM160808ALCR47A | INDC1608X75N | Inductor | https://www.lcsc.com/product-detail/C695609.html?s_z=n_C695609『 』https://www.mouser.com/ProductDetail/TDK/TFM160808ALC-R47MTAA?qs=3SnDZBG9J%252B6tokb499UWsQ%3D%3D | $0.357 | $1.785
18 | R1 | 1 | YAGEO | RC0402FR-07100KL | 100k | C60491 | R_0402_1005Metric | Resistor | https://www.lcsc.com/product-detail/C60491.html?s_z=n_C60491 | $0.032 | $0.160
19 | R12,R11 | 2 | YAGEO | RC0402FR-072K2L | 2k2 | C114762 | R_0402_1005Metric | Resistor | https://www.lcsc.com/product-detail/C114762.html?s_z=n_C114762 | $0.019 | $0.190
20 | R13,R17 | 2 | YAGEO | RC0402FR-0710KL | 10k | C60490 | R_0402_1005Metric | Resistor | https://www.lcsc.com/product-detail/C60490.html?s_z=n_C60490 | $0.019 | $0.190
21 | R14,R16 | 2 | YAGEO | RC0402FR-074K7L | 4k7 | C105871 | R_0402_1005Metric | Resistor | https://www.lcsc.com/product-detail/C105871.html?s_z=n_C105871 | $0.019 | $0.190
22 | R4,R5 | 2 | YAGEO | RC0402FR-075K1L | 5k1 | C105872 | R_0402_1005Metric | Resistor | https://www.lcsc.com/product-detail/C105872.html?s_z=n_C105872 | $0.019 | $0.190
23 | S1,S2 | 2 | C&K | NANOT160AS | NANOT160AS | C2760981『 』611-NANOT160AS | NANOT160AS | Micro Switch | https://www.lcsc.com/product-detail/C2760981.html?s_z=n_C2760981『 』https://www.mouser.com/ProductDetail/CK/NANOT160AS?qs=OlC7AqGiEDnK60t%2FC6IJyA%3D%3D | $0.686 | $6.860 | 7-10 Workdays
24 | U1 | 1 | Espressif Systems | ESP32-S3-MINI-1U-N8 | ESP32 S3 Mini 1U 8MB Flash | C2980299 | ESP32-S2-MINI-1U | MCU Module | https://www.lcsc.com/product-detail/C2980299.html?s_z=n_ESP32-S3-MINI | $6.883 | $34.415 |  |  | The quoted part number is [ESP32-S3-MINI-1U-N8], not [ESP32-S2] as specified in description
25 | U2,U3 | 2 | Texas Instruments | LM66100DCK | Ideal Diode, Input Polarity Prot. | C2869734『 』595-LM66100DCKT | SOT-363_SC-70-6 | Ideal Diode | https://www.lcsc.com/product-detail/C2869734.html?s_z=n_C2869734『 』https://www.mouser.com/ProductDetail/Texas-Instruments/LM66100DCKT?qs=vLWxofP3U2zoiBCtDTudjw%3D%3D | $0.221 | $2.210
26 | U4 | 1 | Texas Instruments | TMP112AIDRLR | TMP112 | C28927 | SOT-563 | Temp Sensor | https://www.lcsc.com/product-image/C28927.html | $1.650 | $8.250
 |  |  |  |  |  |  |  |  |  | Component Cost | $86.20

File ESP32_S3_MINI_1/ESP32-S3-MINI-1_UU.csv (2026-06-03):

Id | Designator | Footprint | Quantity | Designation | Supplier and ref
1 | C1, C2, C5 | C_0402_1005Metric | 3 | 10uF
2 | C3 | C_0402_1005Metric | 1 | 22uF
3 | C4, C10, C11, C12 | C_0402_1005Metric | 4 | 0u1F
4 | C6 | C_0402_1005Metric | 1 | 10uF
5 | C7 | C_0402_1005Metric | 1 | 1uF
6 | C8 | C_0402_1005Metric | 1 | 1.0uF
7 | C9 | C_0402_1005Metric | 1 | 4u7F
8 | C14 | C_0402_1005Metric | 1 | 10nF
9 | C15 | C_0402_1005Metric | 1 | 0.1uF
10 | D1 | D_SOD-923 | 1 | ESD9B5.0ST5G
11 | D2 | LED_0402_1005Metric | 1 | LED GRN
12 | D3 | LED_0402_1005Metric | 1 | LED RED
13 | D4, D5 | LED_0402_1005Metric | 2 | LED
14 | D6 | WS2812_2020 | 1 | WS2812B
15 | D7, D8 | SODFL1006X40N | 2 | ESD9101P2T5G
16 | IC1 | TPS6282533DMQR | 1 | TPS6282533DMQR
17 | IC2 | SON40P220X200X80-11N | 1 | BQ25185DLHR
18 | J1 | JST_1x02_P2.0mm_Horizontal_SMD | 1 | JST_2mm_LiPo
19 | J2 | USB412003C | 1 | USB4120-03-C
20 | J3 | JST_1x04_P1.0mm_Vertical_SMD | 1 | Qwiic_Vertical
21 | J4, J7 | Castellated_1x01_P2.54mm_D0.80mm | 2 | Castellated_1x01
22 | J8 | Castellated_1x16_P2.54mm_D0.80mm | 1 | Castellated_1x16
23 | J9 | Castellated_1x18_P2.54mm_D0.80mm | 1 | Castellated_1x18
24 | L1 | INDC1608X75N | 1 | TFM160808ALC-R47MTAA
25 | R1, R8 | R_0402_1005Metric | 2 | 100k
26 | R2 | R_0402_1005Metric | 1 | 18k
27 | R3 | R_0402_1005Metric | 1 | 300
28 | R4, R5 | R_0402_1005Metric | 2 | 5k1
29 | R9, R10, R11, R12 | R_0402_1005Metric | 4 | 2k2
30 | R13, R17, TH1 | R_0402_1005Metric | 3 | 10k
31 | R14, R16 | R_0402_1005Metric | 2 | 4k7
32 | S1, S2 | NANOT160AS | 2 | NANOT160AS
33 | U1, U5 | SOT-363_SC-70-6 | 2 | LM66100DCK
34 | U2 | ESP32-S2-MINI-1 | 1 | ESP32-S3-MINI-1
35 | U3 | DFN-8_2x2mm_P0.5mm_EP1.2x0.8mm | 1 | MAX17048
36 | U4 | SOT-563 | 1 | TMP112A

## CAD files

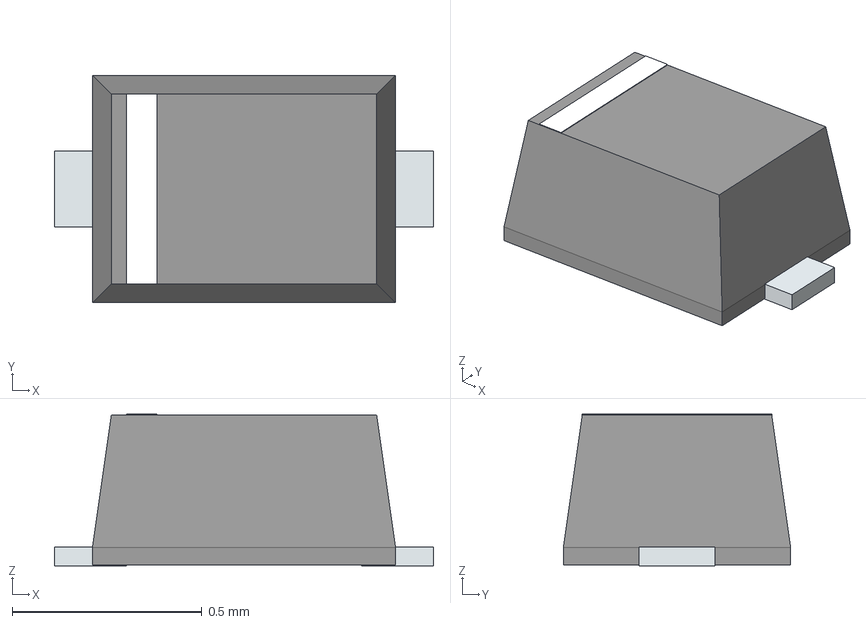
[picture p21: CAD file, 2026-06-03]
ESP32-C6/3D/ESD9101P2T5G.stp
1.00 x 0.6 x 0.4 mm
PinKIdent
PinK
PinA

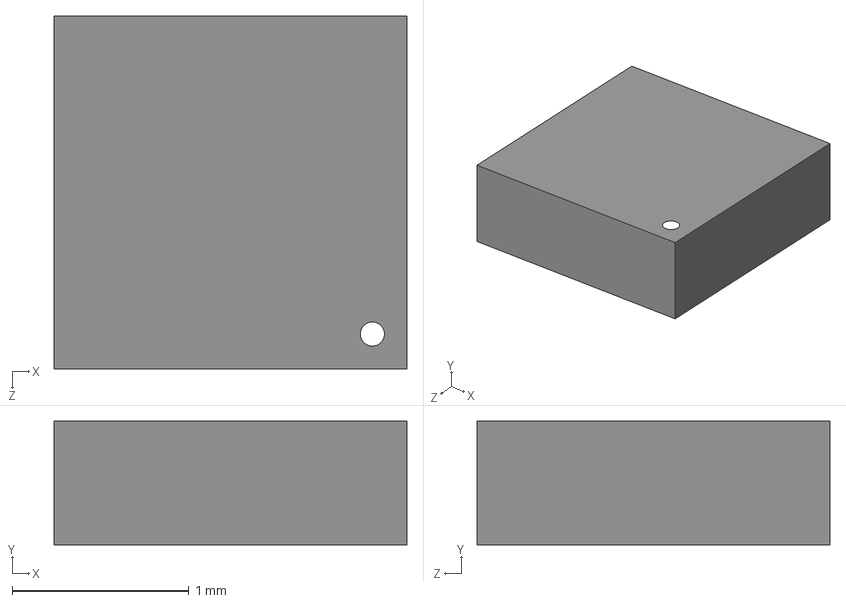
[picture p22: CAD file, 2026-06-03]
ESP32_S3_MINI_1U/3d/LIS2DW12TR.step
2.00 x 0.7 x 2.00 mm

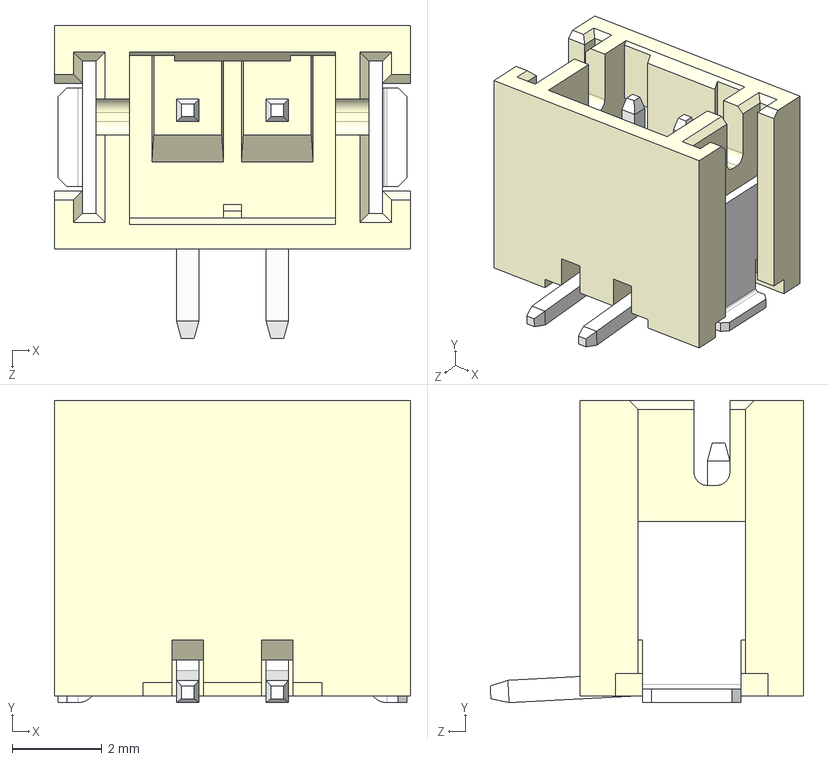
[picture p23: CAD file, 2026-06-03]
ESP32-C6/3D/B2B-PH-SM4-TB__LF__SN_.stp
7.95 x 6.75 x 7.00 mm

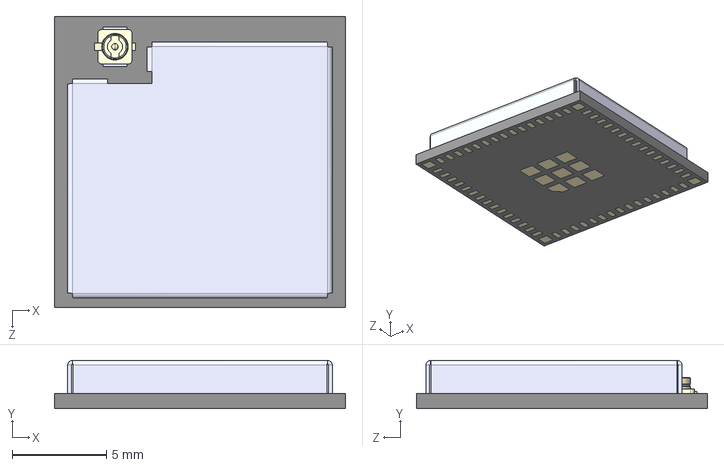
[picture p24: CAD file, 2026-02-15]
ESP32_S3_MINI_1/3d/ESP32-S3-MINI-1U-N8.STEP
15.4 x 2.55 x 15.4 mm
ESP32-S3-MINI-1U-N8_ESP32-C3-MINI-1-N4
antenna jack

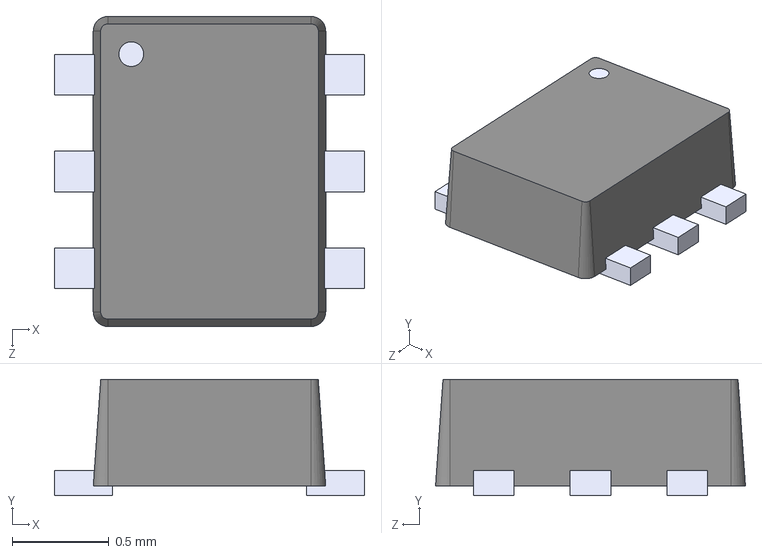
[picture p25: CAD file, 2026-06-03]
ESP32_S3_MINI_1U/3d/TMP112AIDRLT.step
1.60 x 0.6 x 1.60 mm

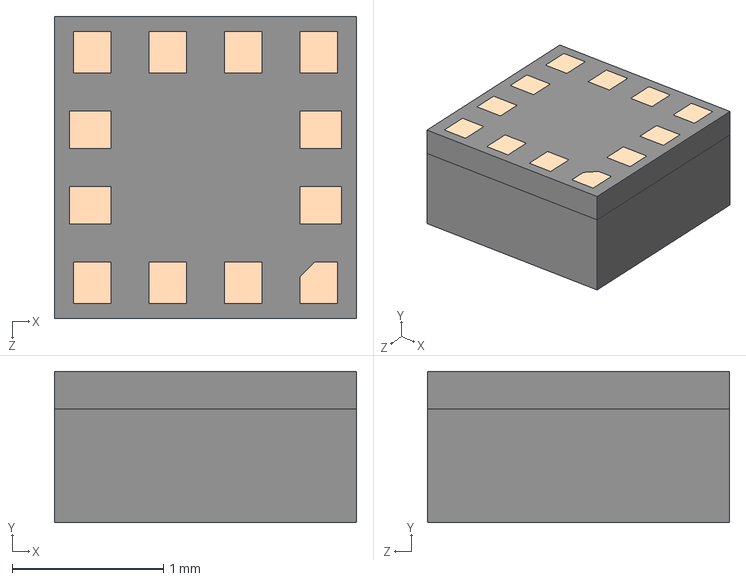
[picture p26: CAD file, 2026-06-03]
ESP32-C6/3D/LIS2DW12TR.stp
2.00 x 1.00 x 2.00 mm

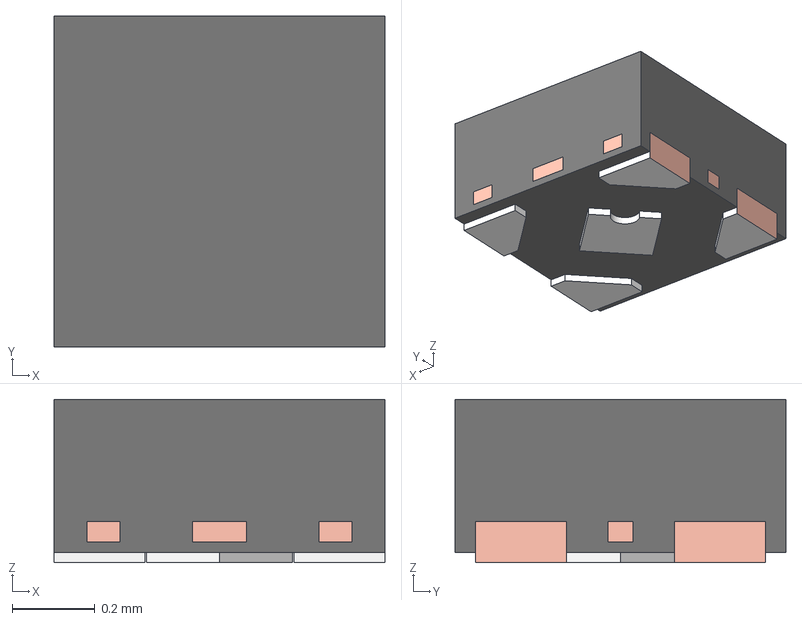
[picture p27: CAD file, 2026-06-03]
ESP32-C6/3D/DPW0005B.stp
0.8 x 0.8 x 0.395 mm
BODY-SON
FRAME-DPW0005B
PIN1-ID

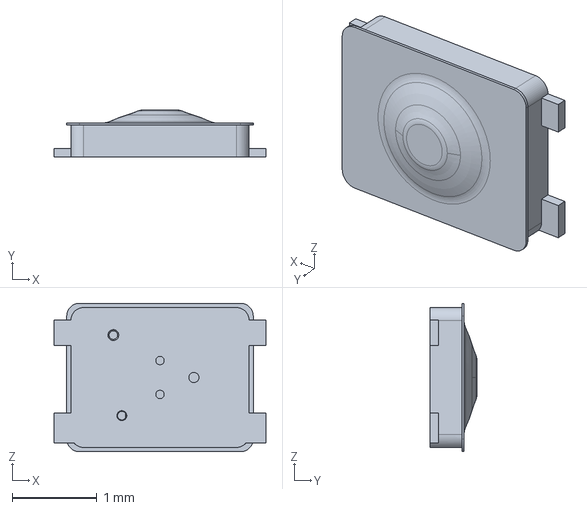
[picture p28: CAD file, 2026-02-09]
ESP32_S3_MINI_1/3d/NANOT160AS.step
2.50 x 0.55 x 1.75 mm

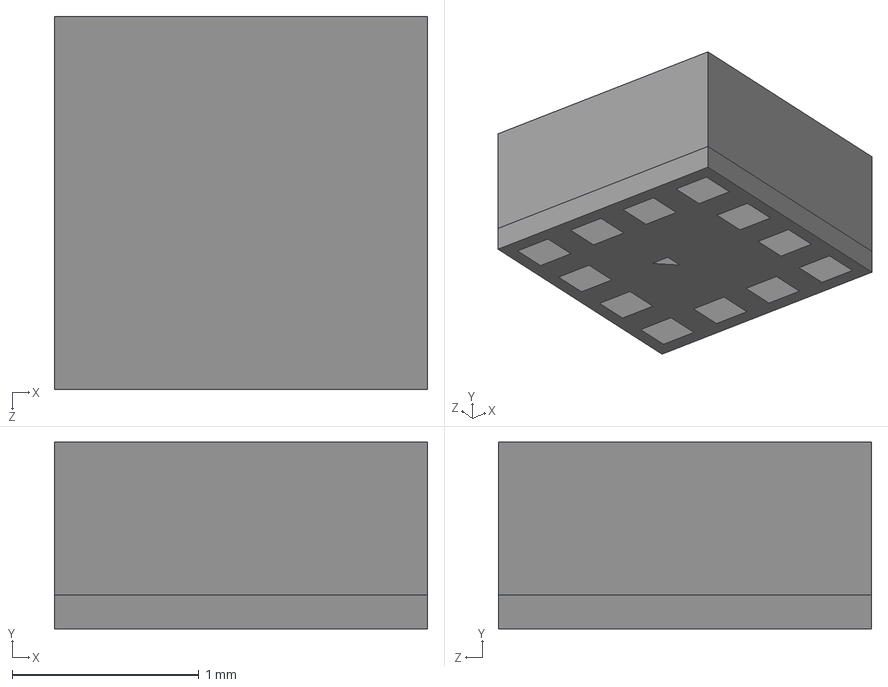
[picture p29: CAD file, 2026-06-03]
ESP32_S3_MINI_1U/3d/BMA400.step
2.00 x 1.00 x 2.00 mm

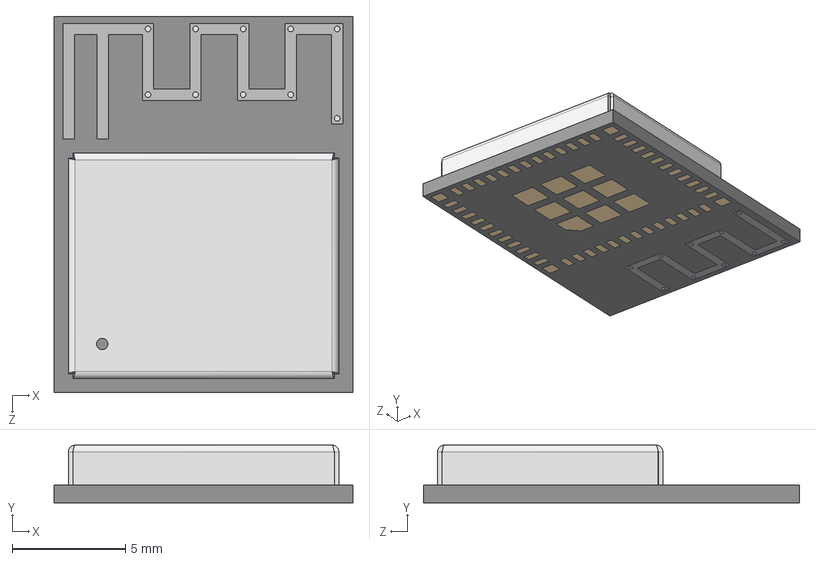
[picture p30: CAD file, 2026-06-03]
ESP32-C6/3D/ESP32-C6-MINI-1-N4.stp
13.2 x 2.55 x 16.6 mm

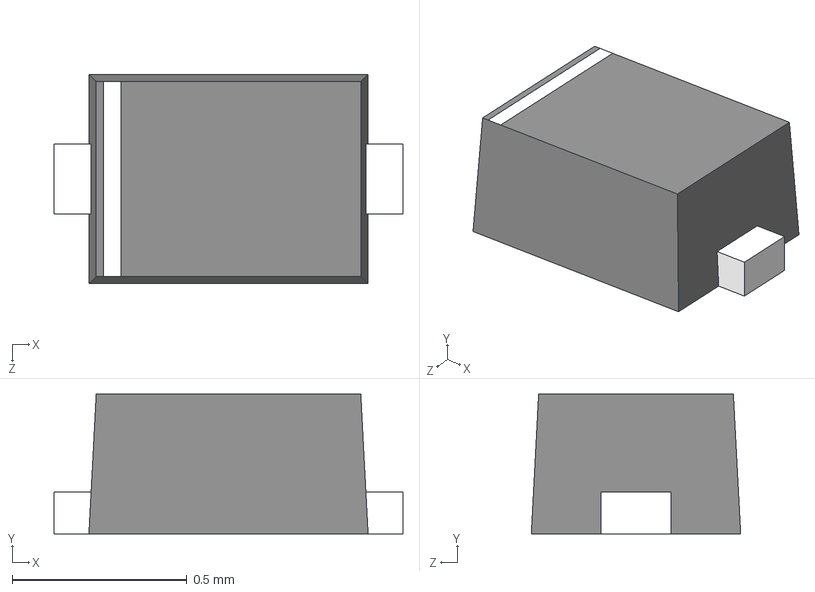
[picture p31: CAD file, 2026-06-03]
ESP32_S3_MINI_1U/3d/ESD9B5.0ST5G.step
1 x 0.4 x 0.6 mm

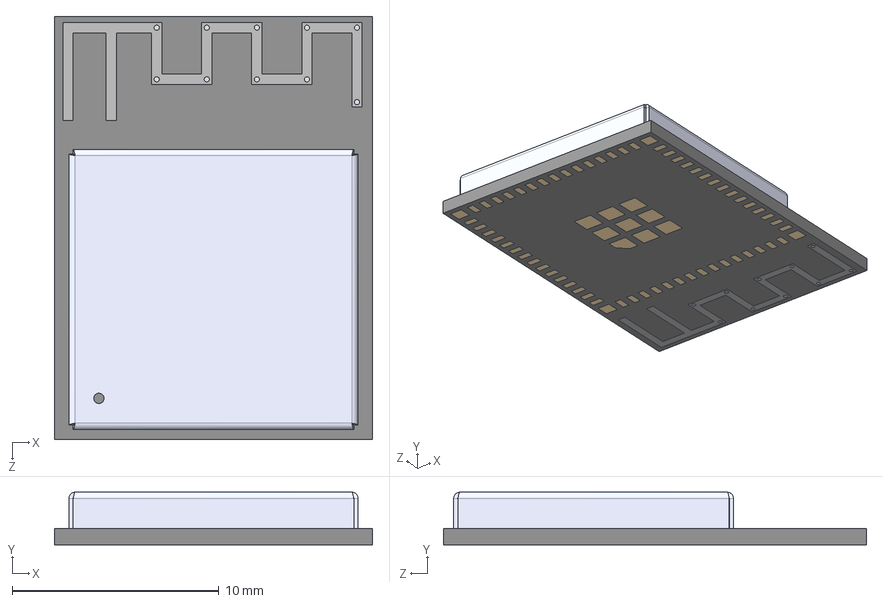
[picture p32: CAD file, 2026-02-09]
ESP32_S3_MINI_1/3d/ESP32-S3-MINI-1-N8.stp
15.4 x 2.55 x 20.5 mm

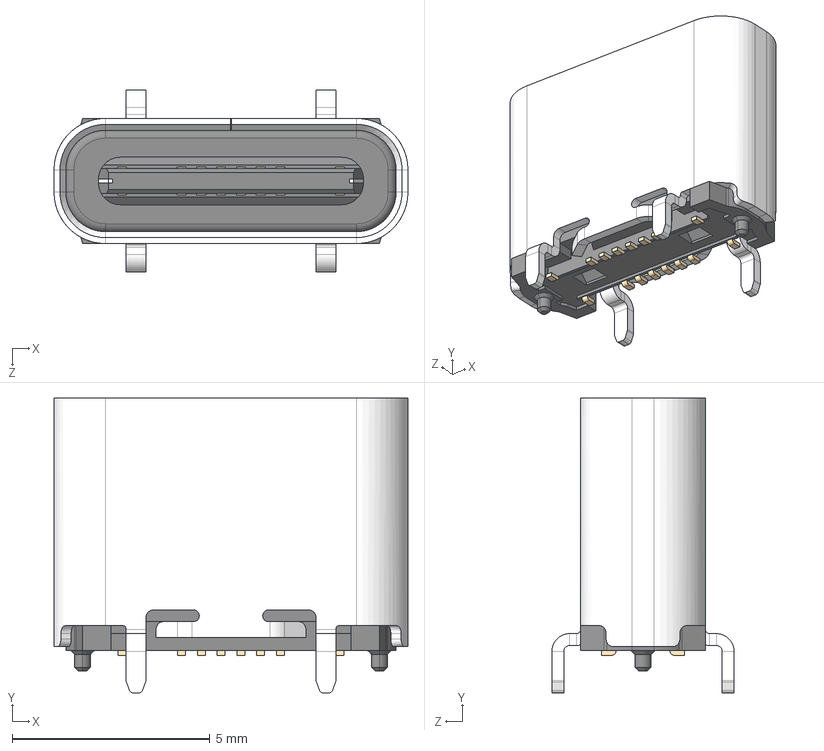
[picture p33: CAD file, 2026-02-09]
ESP32_S3_MINI_1/3d/USB4120-03-C.step
8.94 x 7.45 x 4.60 mm

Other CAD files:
ESP32-C6/3D/BQ25185DLHR.stp
ESP32-C6/3D/CSD25310Q2.step
ESP32-C6/3D/DFE201210S-2R2M=P2.stp
ESP32-C6/3D/TFM160808ALC-R47MTAA.step
ESP32-C6/3D/TFM160808ALC-R47MTAA.stp
ESP32-C6/3D/TPS6282533DMQR.step
ESP32_S3_MINI_1/3d/BQ25185DLHR.step
ESP32_S3_MINI_1/3d/TFM160808ALC-R47MTAA.step
ESP32_S3_MINI_1/3d/TFM160808ALC-R47MTAA.stp
ESP32_S3_MINI_1/3d/TPS6282533DMQR.step
ESP32_S3_MINI_1U/3d/BQ25185DLHR.step
ESP32_S3_MINI_1U/3d/CSD25310Q2.step
ESP32_S3_MINI_1U/3d/DFE201610E-4R7M=P2.step
ESP32_S3_MINI_1U/3d/TFM160808ALC-R47MTAA.step
ESP32_S3_MINI_1U/3d/TFM160808ALC-R47MTAA.stp
ESP32_S3_MINI_1U/3d/TPS6282533DMQR.step

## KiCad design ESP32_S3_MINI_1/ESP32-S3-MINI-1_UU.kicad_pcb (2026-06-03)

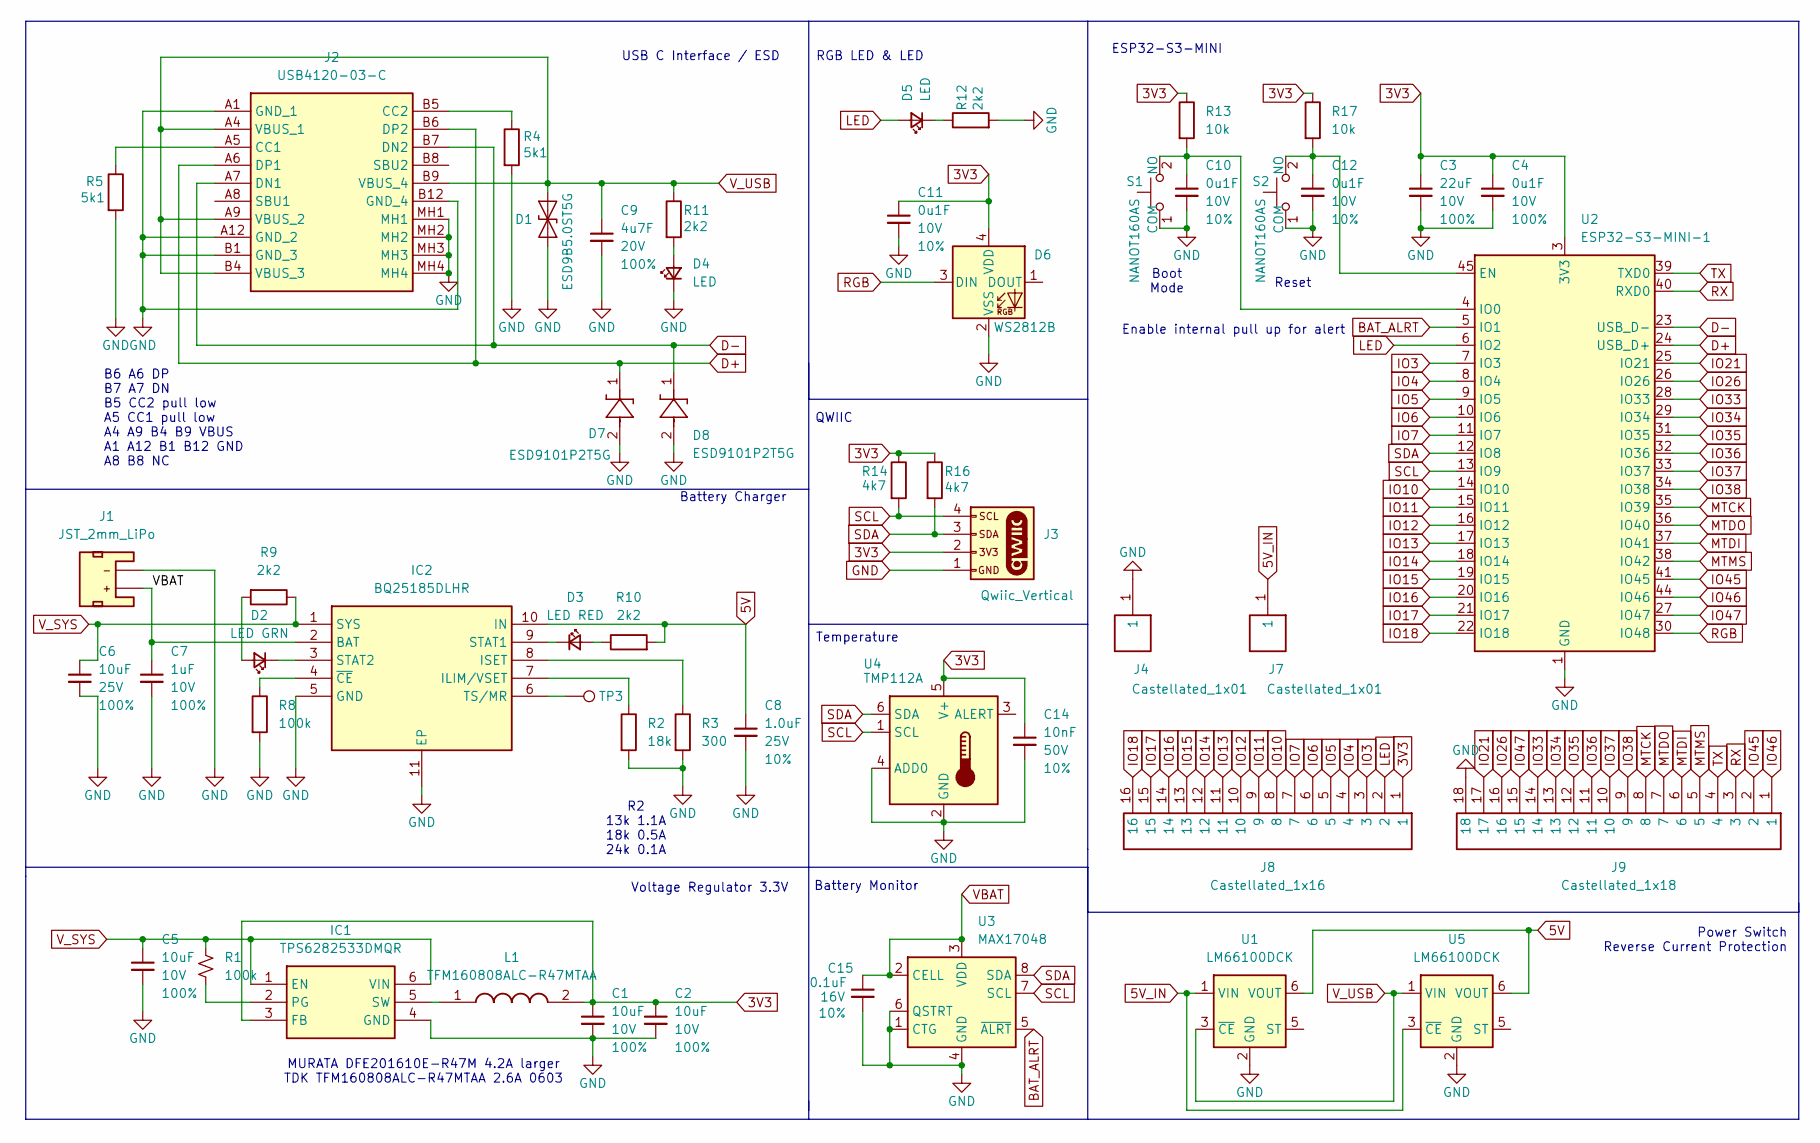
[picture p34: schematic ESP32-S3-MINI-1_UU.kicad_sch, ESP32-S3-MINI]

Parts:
C1, C2, C5: 10uF; C_0402_1005Metric; Voltage 10V; Tolerance 100%
C3: 22uF; C_0402_1005Metric; Voltage 10V; Tolerance 100%
C4: 0u1F; C_0402_1005Metric; Voltage 10V; Tolerance 100%
C6: 10uF; C_0402_1005Metric; Voltage 25V; Tolerance 100%
C7: 1uF; C_0402_1005Metric; Voltage 10V; Tolerance 100%
C8: 1.0uF; C_0402_1005Metric; Voltage 25V; Tolerance 10%
C9: 4u7F; C_0402_1005Metric; Voltage 20V; Tolerance 100%
C10, C11, C12: 0u1F; C_0402_1005Metric; Voltage 10V; Tolerance 10%
C14: 10nF; C_0402_1005Metric; Voltage 50V; Tolerance 10%
C15: 0.1uF; C_0402_1005Metric; Voltage 16V; Tolerance 10%
D1: ESD9B5.0ST5G; D_SOD-923
D2: LED GRN; LED_0402_1005Metric
D3: LED RED; LED_0402_1005Metric
D4, D5: LED; LED_0402_1005Metric
D6: WS2812B; WS2812_2020
D7, D8: ESD9101P2T5G; SODFL1006X40N; Manufacturer_Part_Number ESD9101P2T5G; Mouser Part Number 863-ESD9101P2T5G
IC1: TPS6282533DMQR; Manufacturer_Part_Number TPS6282533DMQR; Mouser Part Number 595-TPS6282533DMQR
IC2: BQ25185DLHR; SON40P220X200X80-11N; Manufacturer_Part_Number BQ25185DLHR; Mouser Part Number 595-BQ25185DLHR
J1: JST_2mm_LiPo; JST_1x02_P2.0mm_Horizontal_SMD
J2: USB4120-03-C; USB412003C; Manufacturer_Part_Number USB4120-03-C; Mouser Part Number 640-USB4120-03-C
J3: Qwiic_Vertical; JST_1x04_P1.0mm_Vertical_SMD
J4, J7: Castellated_1x01; Castellated_1x01_P2.54mm_D0.80mm
J8: Castellated_1x16; Castellated_1x16_P2.54mm_D0.80mm
J9: Castellated_1x18; Castellated_1x18_P2.54mm_D0.80mm
L1: TFM160808ALC-R47MTAA; INDC1608X75N; Manufacturer_Part_Number TFM160808ALC-R47MTAA; Mouser Part Number 810-TFM160808ALCR47A
R1, R8: 100k; R_0402_1005Metric
R2: 18k; R_0402_1005Metric
R3: 300; R_0402_1005Metric
R4, R5: 5k1; R_0402_1005Metric
R9, R10, R11, R12: 2k2; R_0402_1005Metric
R13, R17: 10k; R_0402_1005Metric
R14, R16: 4k7; R_0402_1005Metric
S1, S2: NANOT160AS; Mouser Part Number 611-NANOT160AS
TP3: TestPoint; TestPoint_Pad_1.0x1.0mm
U1, U5: LM66100DCK; SOT-363_SC-70-6
U2: ESP32-S3-MINI-1; ESP32-S2-MINI-1
U3: MAX17048; DFN-8_2x2mm_P0.5mm_EP1.2x0.8mm
U4: TMP112A; SOT-563

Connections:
3V3: C1.1, C2.1, C3.1, C4.1, C11.1, C14.1, D6.4 (VDD), IC1.3 (FB), J3.2, J8.1, L1.2, R13.1, R14.1, R16.1, R17.1, U2.3 (3V3), U4.5 (V+)
5V: C8.1, IC2.10 (IN), R10.2, U1.6 (VOUT), U5.6 (VOUT)
5V_IN: J7.1 (1_1), U1.1 (VIN), U5.3 (~CE)
BAT_ALRT: U2.5 (IO1), U3.5 (~ALRT)
D+: D7.1, J2.A6 (DP1), J2.B6 (DP2), U2.24 (USB_D+)
D-: D8.1, J2.A7 (DN1), J2.B7 (DN2), U2.23 (USB_D-)
GND: C1.2, C2.2, C3.2, C4.2, C5.2, C6.2, C7.2, C8.2, C9.2, C10.2, C11.2, C12.2, C14.2, C15.2, D1.2 (A2), D4.1 (K), D6.2 (VSS), D7.2, D8.2, IC1.4 (GND), IC2.5 (GND), IC2.11 (EP), J1.1 (-), J2.A1 (GND_1), J2.A12 (GND_2), J2.B1 (GND_3), J2.B12 (GND_4), J2.MH1, J2.MH2, J2.MH3, J2.MH4, J3.1, J4.1 (1_1), J9.18, R2.2, R3.2, R4.2, R5.2, R8.2, R12.2, S1.1 (COM), S2.1 (COM), U1.2 (GND), U2.1 (GND), U2.2 (GND), U2.42 (GND), U2.43 (GND), U2.46 (GND), U2.47 (GND), U2.48 (GND), U2.49 (GND), U2.50 (GND), U2.51 (GND), U2.52 (GND), U2.53 (GND), U2.54 (GND), U2.55 (GND), U2.56 (GND), U2.57 (GND), U2.58 (GND), U2.59 (GND), U2.60 (GND), U2.61 (GND), U2.62 (GND), U2.63 (GND), U2.64 (GND), U2.65 (GND), U3.1 (CTG), U3.4 (GND), U3.6 (QSTRT), U3.9 (GND), U4.2 (GND), U4.4 (ADD0), U5.2 (GND)
IO3: J8.3, U2.7 (IO3)
IO4: J8.4, U2.8 (IO4)
IO5: J8.5, U2.9 (IO5)
IO6: J8.6, U2.10 (IO6)
IO7: J8.7, U2.11 (IO7)
IO10: J8.8, U2.14 (IO10)
IO11: J8.9, U2.15 (IO11)
IO12: J8.10, U2.16 (IO12)
IO13: J8.11, U2.17 (IO13)
IO14: J8.12, U2.18 (IO14)
IO15: J8.13, U2.19 (IO15)
IO16: J8.14, U2.20 (IO16)
IO17: J8.15, U2.21 (IO17)
IO18: J8.16, U2.22 (IO18)
IO21: J9.17, U2.25 (IO21)
IO26: J9.16, U2.26 (IO26)
IO33: J9.14, U2.28 (IO33)
IO34: J9.13, U2.29 (IO34)
IO35: J9.12, U2.31 (IO35)
IO36: J9.11, U2.32 (IO36)
IO37: J9.10, U2.33 (IO37)
IO38: J9.9, U2.34 (IO38)
IO45: J9.2, U2.41 (IO45)
IO46: J9.1, U2.44 (IO46)
IO47: J9.15, U2.27 (IO47)
LED: D5.2 (A), J8.2, U2.6 (IO2)
MTCK: J9.8, U2.35 (IO39)
MTDI: J9.6, U2.37 (IO41)
MTDO: J9.7, U2.36 (IO40)
MTMS: J9.5, U2.38 (IO42)
unnamed: D2.2 (A), R9.2
unnamed: D2.1 (K), IC2.3 (STAT2)
unnamed: D3.2 (A), R10.1
unnamed: D3.1 (K), IC2.9 (STAT1)
unnamed: D4.2 (A), R11.2
unnamed: D5.1 (K), R12.1
unnamed: IC1.2 (PG), R1.1
unnamed: IC1.5 (SW), L1.1
unnamed: IC2.7 (ILIM/VSET), R2.1
unnamed: IC2.8 (ISET), R3.1
unnamed: IC2.6 (TS/MR), TP3.1 (1_1)
unnamed: IC2.4 (~CE), R8.1
unnamed: J2.A5 (CC1), R5.1
unnamed: J2.B5 (CC2), R4.1
unnamed: C10.1, R13.2, S1.2 (NO), U2.4 (IO0)
unnamed: C12.1, R17.2, S2.2 (NO), U2.45 (EN)
RGB: D6.3 (DIN), U2.30 (IO48)
RX: J9.3, U2.40 (RXD0)
SCL: J3.4, R14.2, U2.13 (IO9), U3.7 (SCL), U4.1 (SCL)
SDA: J3.3, R16.2, U2.12 (IO8), U3.8 (SDA), U4.6 (SDA)
TX: J9.4, U2.39 (TXD0)
VBAT: C7.1, C15.1, IC2.2 (BAT), J1.2 (+), U3.2 (CELL), U3.3 (VDD)
V_SYS: C5.1, C6.1, IC1.1 (EN), IC1.6 (VIN), IC2.1 (SYS), R1.2, R9.1
V_USB: C9.1, D1.1 (A1), J2.A4 (VBUS_1), J2.A9 (VBUS_2), J2.B4 (VBUS_3), J2.B9 (VBUS_4), R11.1, U1.3 (~CE), U5.1 (VIN)

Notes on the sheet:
Voltage Regulator 3.3V
Boot Mode
ESP32-S3-MINI
Battery Monitor
Power Switch Reverse Current Protection
MURATA DFE201610E-R47M 4.2A larger TDK TFM160808ALC-R47MTAA 2.6A 0603
Temperature
RGB LED & LED
Reset
R2 13k 1.1A 18k 0.5A 24k 0.1A
Battery Charger
Enable internal pull up for alert
B6 A6 DP B7 A7 DN B5 CC2 pull low A5 CC1 pull low A4 A9 B4 B9 VBUS A1 A12 B1 B12 GND A8 B8 NC
USB C Interface / ESD
QWIIC

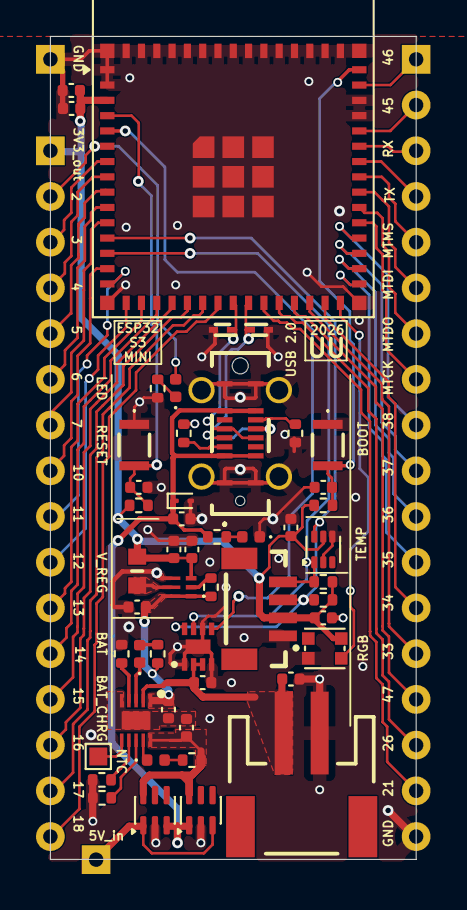
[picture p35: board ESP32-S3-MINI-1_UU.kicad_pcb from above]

Board: 2 copper layers, 20.3 x 45.7 mm, 54 parts (0 on the bottom side), 61 nets.

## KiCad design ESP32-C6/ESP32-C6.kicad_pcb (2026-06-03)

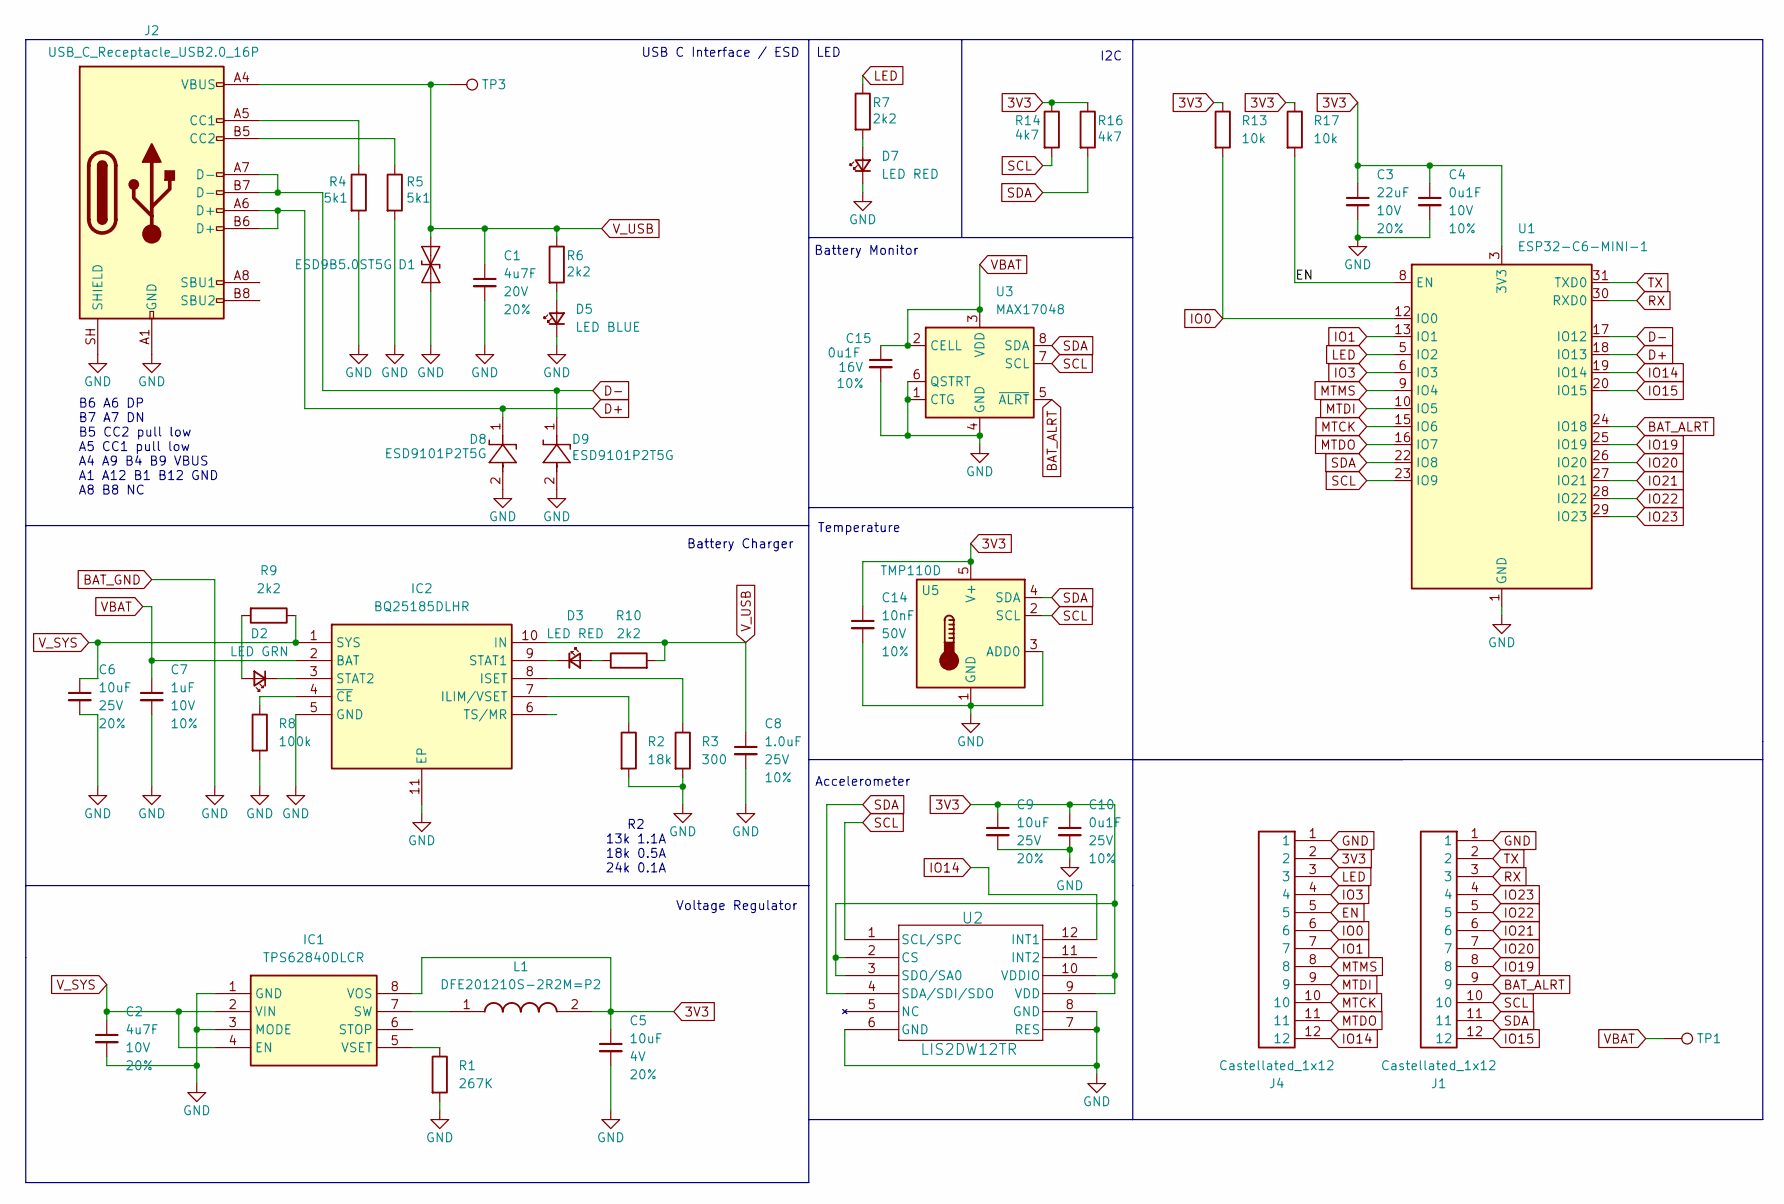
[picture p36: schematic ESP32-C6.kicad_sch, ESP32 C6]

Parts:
C1: 4u7F; C_0402_1005Metric; Voltage 20V; Tolerance 20%
C2: 4u7F; C_0402_1005Metric; Voltage 10V; Tolerance 20%
C3: 22uF; C_0402_1005Metric; Voltage 10V; Tolerance 20%
C4: 0u1F; C_0402_1005Metric; Voltage 10V; Tolerance 10%
C5: 10uF; C_0402_1005Metric; Voltage 4V; Tolerance 20%
C6, C9: 10uF; C_0402_1005Metric; Voltage 25V; Tolerance 20%
C7: 1uF; C_0402_1005Metric; Voltage 10V; Tolerance 10%
C8: 1.0uF; C_0402_1005Metric; Voltage 25V; Tolerance 10%
C10: 0u1F; C_0402_1005Metric; Voltage 25V; Tolerance 10%
C14: 10nF; C_0201_0603Metric; Voltage 50V; Tolerance 10%
C15: 0u1F; C_0402_1005Metric; Voltage 16V; Tolerance 10%
D1: ESD9B5.0ST5G; D_SOD-923
D2: LED GRN; LED_0402_1005Metric
D3, D7: LED RED; LED_0402_1005Metric
D5: LED BLUE; LED_0402_1005Metric
D8, D9: ESD9101P2T5G; SODFL1006X40N; Manufacturer_Part_Number ESD9101P2T5G; Mouser Part Number 863-ESD9101P2T5G
IC1: TPS62840DLCR; SON50P150X200X100-8N-D; Manufacturer_Part_Number TPS62840DLCR; Mouser Part Number 595-TPS62840DLCR
IC2: BQ25185DLHR; SON40P220X200X80-11N; Manufacturer_Part_Number BQ25185DLHR; Mouser Part Number 595-BQ25185DLHR
J1, J4: Castellated_1x12; Castellated_1x12_P2.54mm_D0.80mm
J2: USB_C_Receptacle_USB2.0_16P; USB_C_Receptacle_GCT_USB4105-xx-A_16P_TopMnt_Horizontal
L1: DFE201210S-2R2M=P2; DFE201210S1R0MP2; Manufacturer_Part_Number DFE201210S-2R2M=P2; Mouser Part Number 81-DFE201210S-2R2MP2
R1: 267K; R_0402_1005Metric
R2: 18k; R_0402_1005Metric
R3: 300; R_0402_1005Metric
R4, R5: 5k1; R_0402_1005Metric
R6, R7, R9, R10: 2k2; R_0402_1005Metric
R8: 100k; R_0402_1005Metric
R13, R17: 10k; R_0402_1005Metric
R14, R16: 4k7; R_0402_1005Metric
TP1, TP3: TestPoint; TestPoint_Pad_1.5x1.5mm
U1: ESP32-C6-MINI-1
U2: LIS2DW12TR; LGA-12_2X2X0P7_STM
U3: MAX17048; DFN-8_2x2mm_P0.5mm_EP1.2x0.8mm
U5: TMP110D; Texas_X2SON-5_0.8x0.8mm_P0.48mm

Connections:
3V3: C3.1, C4.1, C5.1, C9.1, C10.1, C14.1, IC1.8 (VOS), J4.2, L1.2, R13.1, R14.1, R16.1, R17.1, U1.3 (3V3), U2.2 (CS), U2.3 (SDO/SA0), U2.9 (VDD), U2.10 (VDDIO), U5.5 (V+)
BAT_ALRT: J1.9, U1.24 (IO18), U3.5 (~ALRT)
BAT_GND: C1.2, C2.2, C3.2, C4.2, C5.2, C6.2, C7.2, C8.2, C9.2, C10.2, C14.2, C15.2, D1.2 (A2), D5.1 (K), D7.1 (K), D8.2, D9.2, IC1.1 (GND), IC1.3 (MODE), IC2.5 (GND), IC2.11 (EP), J1.1, J2.A1 (GND), J2.A12 (GND), J2.B1 (GND), J2.B12 (GND), J2.SH (SHIELD), J4.1, R1.2, R2.2, R3.2, R4.2, R5.2, R8.2, U1.1 (GND), U1.2 (GND), U1.11 (GND), U1.14 (GND), U1.36 (GND), U1.37 (GND), U1.38 (GND), U1.39 (GND), U1.40 (GND), U1.41 (GND), U1.42 (GND), U1.43 (GND), U1.44 (GND), U1.45 (GND), U1.46 (GND), U1.47 (GND), U1.48 (GND), U1.49 (GND), U1.50 (GND), U1.51 (GND), U1.52 (GND), U1.53 (GND), U2.6 (GND), U2.7 (RES), U2.8 (GND), U3.1 (CTG), U3.4 (GND), U3.6 (QSTRT), U3.9 (GND), U5.1 (GND), U5.3 (ADD0)
D+: D8.1, J2.A6 (D+), J2.B6 (D+), U1.18 (IO13)
D-: D9.1, J2.A7 (D-), J2.B7 (D-), U1.17 (IO12)
EN: J4.5, R17.2, U1.8 (EN)
IO0: J4.6, R13.2, U1.12 (IO0)
IO1: J4.7, U1.13 (IO1)
IO3: J4.4, U1.6 (IO3)
IO14: J4.12, U1.19 (IO14), U2.12 (INT1)
IO15: J1.12, U1.20 (IO15)
IO19: J1.8, U1.25 (IO19)
IO20: J1.7, U1.26 (IO20)
IO21: J1.6, U1.27 (IO21)
IO22: J1.5, U1.28 (IO22)
IO23: J1.4, U1.29 (IO23)
LED: J4.3, R7.1, U1.5 (IO2)
MTCK: J4.10, U1.15 (IO6)
MTDI: J4.9, U1.10 (IO5)
MTDO: J4.11, U1.16 (IO7)
MTMS: J4.8, U1.9 (IO4)
unnamed: D2.2 (A), R9.2
unnamed: D2.1 (K), IC2.3 (STAT2)
unnamed: D3.2 (A), R10.1
unnamed: D3.1 (K), IC2.9 (STAT1)
unnamed: D5.2 (A), R6.2
unnamed: D7.2 (A), R7.2
unnamed: IC1.7 (SW), L1.1
unnamed: IC1.5 (VSET), R1.1
unnamed: IC2.7 (ILIM/VSET), R2.1
unnamed: IC2.8 (ISET), R3.1
unnamed: IC2.4 (~CE), R8.1
unnamed: J2.A5 (CC1), R4.1
unnamed: J2.B5 (CC2), R5.1
RX: J1.3, U1.30 (RXD0)
SCL: J1.10, R14.2, U1.23 (IO9), U2.1 (SCL/SPC), U3.7 (SCL), U5.2 (SCL)
SDA: J1.11, R16.2, U1.22 (IO8), U2.4 (SDA/SDI/SDO), U3.8 (SDA), U5.4 (SDA)
TX: J1.2, U1.31 (TXD0)
VBAT: C7.1, C15.1, IC2.2 (BAT), TP1.1 (1_1), U3.2 (CELL), U3.3 (VDD)
V_SYS: C2.1, C6.1, IC1.2 (VIN), IC1.4 (EN), IC2.1 (SYS), R9.1
V_USB: C1.1, C8.1, D1.1 (A1), IC2.10 (IN), J2.A4 (VBUS), J2.A9 (VBUS), J2.B4 (VBUS), J2.B9 (VBUS), R6.1, R10.2, TP3.1 (1_1)

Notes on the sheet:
Accelerometer
B6 A6 DP B7 A7 DN B5 CC2 pull low A5 CC1 pull low A4 A9 B4 B9 VBUS A1 A12 B1 B12 GND A8 B8 NC
Battery Monitor
Voltage Regulator
I2C
LED
Battery Charger
Temperature
R2 13k 1.1A 18k 0.5A 24k 0.1A
USB C Interface / ESD

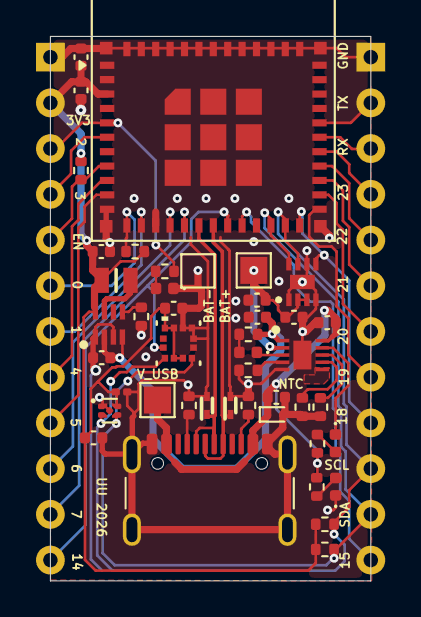
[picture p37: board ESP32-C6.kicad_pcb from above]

Board: 2 copper layers, 17.8 x 30.2 mm, 45 parts (0 on the bottom side), 41 nets.

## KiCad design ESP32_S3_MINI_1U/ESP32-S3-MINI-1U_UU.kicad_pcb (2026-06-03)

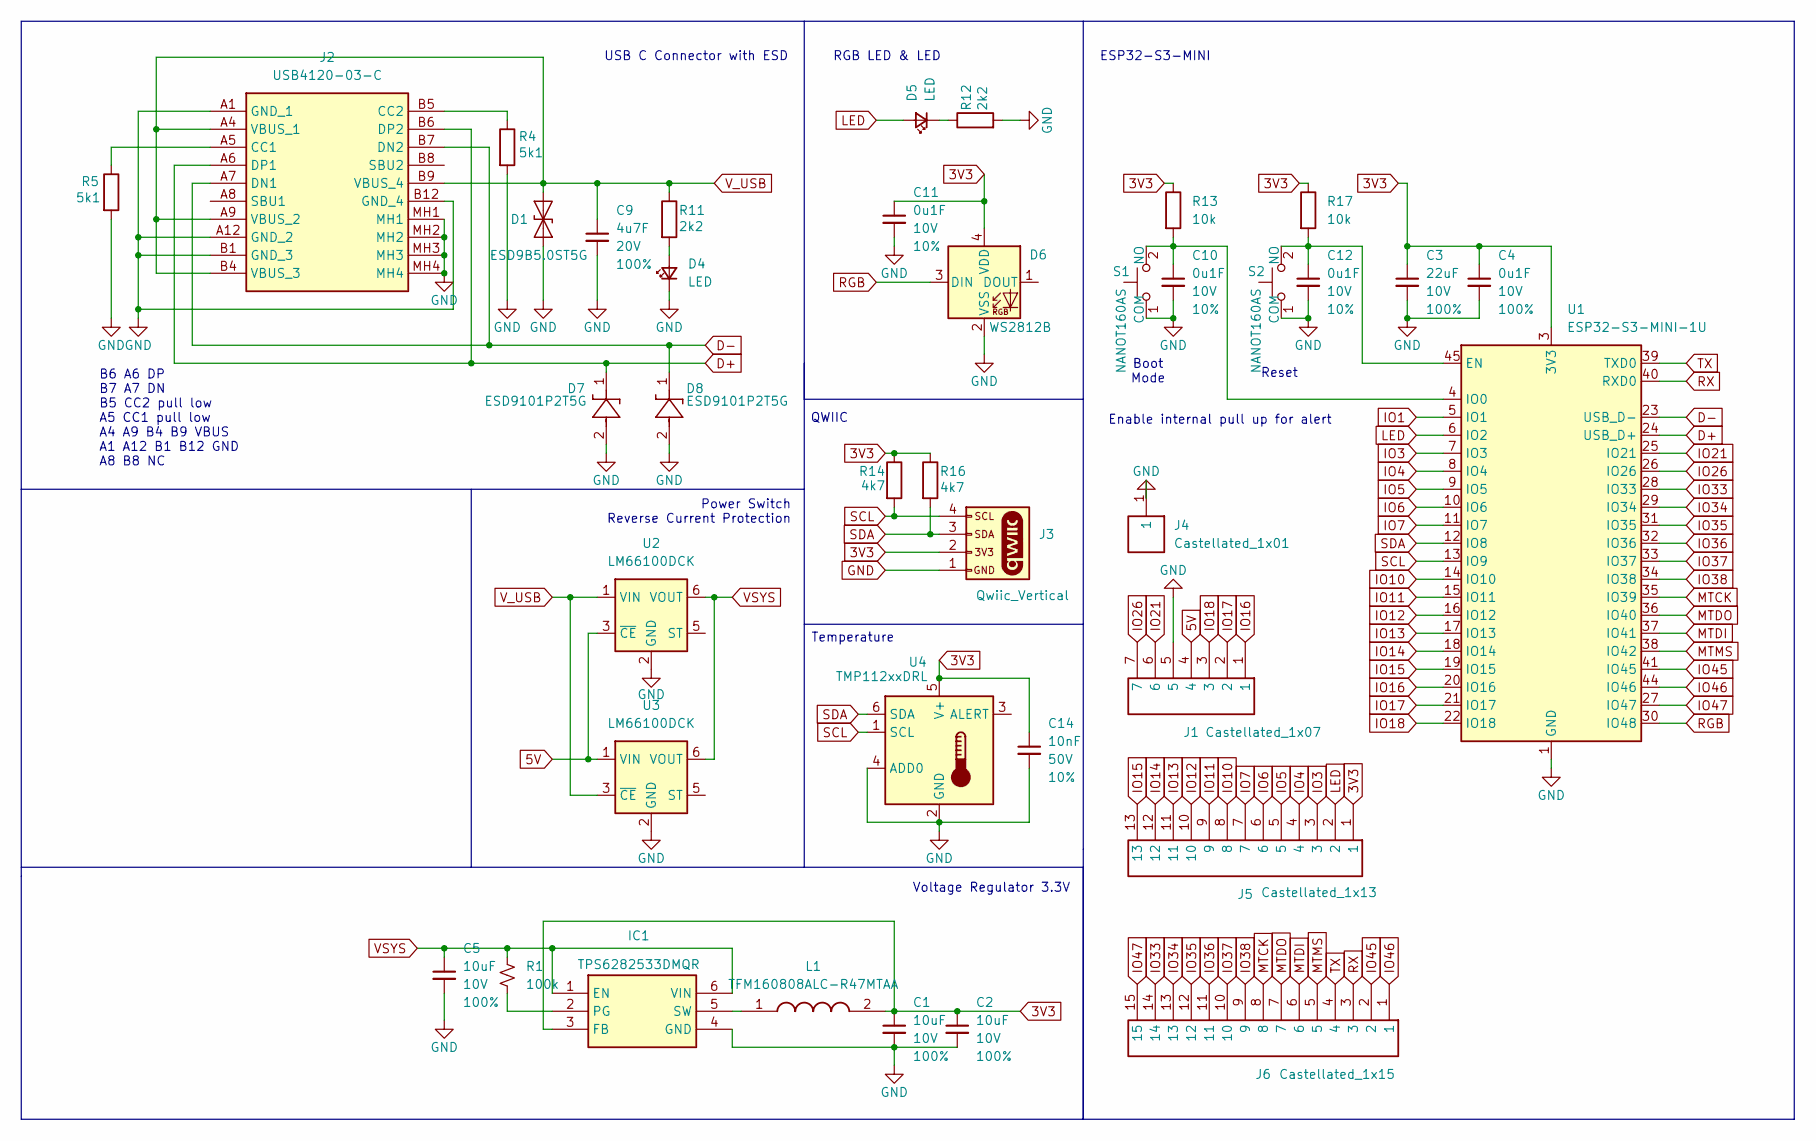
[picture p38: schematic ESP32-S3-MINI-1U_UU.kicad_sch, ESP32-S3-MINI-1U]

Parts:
C1, C2, C5: 10uF; C_0402_1005Metric; Voltage 10V; Tolerance 100%
C3: 22uF; C_0402_1005Metric; Voltage 10V; Tolerance 100%
C4: 0u1F; C_0402_1005Metric; Voltage 10V; Tolerance 100%
C9: 4u7F; C_0402_1005Metric; Voltage 20V; Tolerance 100%
C10, C11, C12: 0u1F; C_0402_1005Metric; Voltage 10V; Tolerance 10%
C14: 10nF; C_0402_1005Metric; Voltage 50V; Tolerance 10%
D1: ESD9B5.0ST5G; SODFL1006X40N
D4, D5: LED; LED_0402_1005Metric
D6: WS2812B; WS2812_2020
D7, D8: ESD9101P2T5G; SODFL1006X40N; Manufacturer_Part_Number ESD9101P2T5G; Mouser Part Number 863-ESD9101P2T5G
IC1: TPS6282533DMQR; Manufacturer_Part_Number TPS6282533DMQR; Mouser Part Number 595-TPS6282533DMQR
J1: Castellated_1x07; Castellated_1x07_P2.54mm_D0.80mm
J2: USB4120-03-C; USB412003C; Manufacturer_Part_Number USB4120-03-C; Mouser Part Number 640-USB4120-03-C
J3: Qwiic_Vertical; JST_1x04_P1.0mm_Vertical_SMD
J4: Castellated_1x01; Castellated_1x01_P2.54mm_D0.80mm
J5: Castellated_1x13; Castellated_1x13_P2.54mm_D0.80mm
J6: Castellated_1x15; Castellated_1x15_P2.54mm_D0.80mm
L1: TFM160808ALC-R47MTAA; INDC1608X75N; Manufacturer_Part_Number TFM160808ALC-R47MTAA; Mouser Part Number 810-TFM160808ALCR47A
R1: 100k; R_0402_1005Metric
R4, R5: 5k1; R_0402_1005Metric
R11, R12: 2k2; R_0402_1005Metric
R13, R17: 10k; R_0402_1005Metric
R14, R16: 4k7; R_0402_1005Metric
S1, S2: NANOT160AS; Mouser Part Number 611-NANOT160AS
U1: ESP32-S3-MINI-1U; ESP32-S2-MINI-1U
U2, U3: LM66100DCK; SOT-363_SC-70-6
U4: TMP112xxDRL; SOT-563

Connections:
3V3: C1.1, C2.1, C3.1, C4.1, C11.1, C14.1, D6.4 (VDD), IC1.3 (FB), J3.2, J5.1, L1.2, R13.1, R14.1, R16.1, R17.1, U1.3 (3V3), U4.5 (V+)
5V: J1.4, U2.3 (~CE), U3.1 (VIN)
D+: D7.1, J2.A6 (DP1), J2.B6 (DP2), U1.24 (USB_D+)
D-: D8.1, J2.A7 (DN1), J2.B7 (DN2), U1.23 (USB_D-)
GND: C1.2, C2.2, C3.2, C4.2, C5.2, C9.2, C10.2, C11.2, C12.2, C14.2, D1.2 (A2), D4.1 (K), D6.2 (VSS), D7.2, D8.2, IC1.4 (GND), J1.5, J2.A1 (GND_1), J2.A12 (GND_2), J2.B1 (GND_3), J2.B12 (GND_4), J2.MH1, J2.MH2, J2.MH3, J2.MH4, J3.1, J4.1 (1_1), R4.2, R5.2, R12.2, S1.1 (COM), S2.1 (COM), U1.1 (GND), U1.2 (GND), U1.42 (GND), U1.43 (GND), U1.46 (GND), U1.47 (GND), U1.48 (GND), U1.49 (GND), U1.50 (GND), U1.51 (GND), U1.52 (GND), U1.53 (GND), U1.54 (GND), U1.55 (GND), U1.56 (GND), U1.57 (GND), U1.58 (GND), U1.59 (GND), U1.60 (GND), U1.61 (GND), U1.62 (GND), U1.63 (GND), U1.64 (GND), U1.65 (GND), U2.2 (GND), U3.2 (GND), U4.2 (GND), U4.4 (ADD0)
IO1: U1.5 (IO1)
IO3: J5.3, U1.7 (IO3)
IO4: J5.4, U1.8 (IO4)
IO5: J5.5, U1.9 (IO5)
IO6: J5.6, U1.10 (IO6)
IO7: J5.7, U1.11 (IO7)
IO10: J5.8, U1.14 (IO10)
IO11: J5.9, U1.15 (IO11)
IO12: J5.10, U1.16 (IO12)
IO13: J5.11, U1.17 (IO13)
IO14: J5.12, U1.18 (IO14)
IO15: J5.13, U1.19 (IO15)
IO16: J1.1, U1.20 (IO16)
IO17: J1.2, U1.21 (IO17)
IO18: J1.3, U1.22 (IO18)
IO21: J1.6, U1.25 (IO21)
IO26: J1.7, U1.26 (IO26)
IO33: J6.14, U1.28 (IO33)
IO34: J6.13, U1.29 (IO34)
IO35: J6.12, U1.31 (IO35)
IO36: J6.11, U1.32 (IO36)
IO37: J6.10, U1.33 (IO37)
IO38: J6.9, U1.34 (IO38)
IO45: J6.2, U1.41 (IO45)
IO46: J6.1, U1.44 (IO46)
IO47: J6.15, U1.27 (IO47)
LED: D5.2 (A), J5.2, U1.6 (IO2)
MTCK: J6.8, U1.35 (IO39)
MTDI: J6.6, U1.37 (IO41)
MTDO: J6.7, U1.36 (IO40)
MTMS: J6.5, U1.38 (IO42)
unnamed: D4.2 (A), R11.2
unnamed: D5.1 (K), R12.1
unnamed: IC1.2 (PG), R1.1
unnamed: IC1.5 (SW), L1.1
unnamed: J2.A5 (CC1), R5.1
unnamed: J2.B5 (CC2), R4.1
unnamed: C10.1, R13.2, S1.2 (NO), U1.4 (IO0)
unnamed: C12.1, R17.2, S2.2 (NO), U1.45 (EN)
RGB: D6.3 (DIN), U1.30 (IO48)
RX: J6.3, U1.40 (RXD0)
SCL: J3.4, R14.2, U1.13 (IO9), U4.1 (SCL)
SDA: J3.3, R16.2, U1.12 (IO8), U4.6 (SDA)
TX: J6.4, U1.39 (TXD0)
VSYS: C5.1, IC1.1 (EN), IC1.6 (VIN), R1.2, U2.6 (VOUT), U3.6 (VOUT)
V_USB: C9.1, D1.1 (A1), J2.A4 (VBUS_1), J2.A9 (VBUS_2), J2.B4 (VBUS_3), J2.B9 (VBUS_4), R11.1, U2.1 (VIN), U3.3 (~CE)

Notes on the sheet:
Voltage Regulator 3.3V
Boot Mode
ESP32-S3-MINI
Power Switch Reverse Current Protection
Temperature
RGB LED & LED
Reset
Enable internal pull up for alert
B6 A6 DP B7 A7 DN B5 CC2 pull low A5 CC1 pull low A4 A9 B4 B9 VBUS A1 A12 B1 B12 GND A8 B8 NC
USB C Connector with ESD
QWIIC

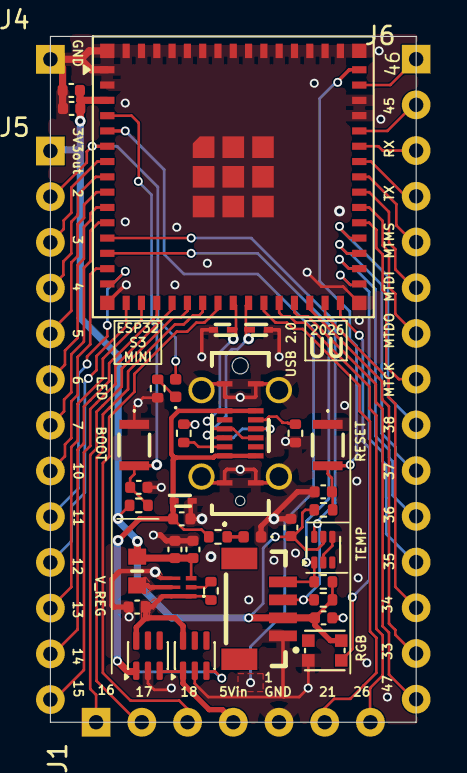
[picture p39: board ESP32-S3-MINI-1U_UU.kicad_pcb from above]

Board: 2 copper layers, 20.3 x 38.1 mm, 39 parts (0 on the bottom side), 50 nets.

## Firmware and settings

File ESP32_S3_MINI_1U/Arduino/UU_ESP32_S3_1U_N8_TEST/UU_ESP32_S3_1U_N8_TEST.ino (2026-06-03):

#include <Wire.h>

// Pin mapping for your custom ESP32-S3-1U-N8 board
static const int PIN_LED = 2;      // Single LED on IO1
static const int PIN_RGB = 48;     // WS2812/NeoPixel data on IO48
static const int RGB_COUNT = 1;    // One onboard RGB LED
static const int PIN_I2C_SDA = 8;   // I2C SDA on IO8
static const int PIN_I2C_SCL = 9;   // I2C SCL on IO9

// TMP102 with ADR tied to GND -> I2C address 0x48
static const uint8_t TMP102_ADDR = 0x48;
static const uint8_t TMP102_REG_TEMP = 0x00;

// Scheduler constants (milliseconds)
static const uint32_t LED_ON_TIME_MS = 120;
static const uint32_t LED_OFF_TIME_MS = 380;
static const uint32_t RGB_UPDATE_INTERVAL_MS = 20;
static const uint32_t TEMP_READ_INTERVAL_MS = 2000;
static const size_t MEM_TEST_BYTES = 8192;
static const uint32_t CDC_FLOOD_TEST_MS = 5000;
static const size_t CDC_FLOOD_CHUNK_BYTES = 256;

// RGB animation constants
static const uint8_t RGB_LED_BRIGHTNESS = 48;
static const uint16_t HUE_MAX = 359;
static const uint16_t HUE_STEP = 2;

bool tmp102Found = false;
bool ledState = false;
uint32_t nextLedEventMs = 0;
uint32_t nextRgbEventMs = 0;
uint32_t nextTempEventMs = 0;
uint16_t hueDeg = 0;

void printBanner() {
  Serial.println();
  Serial.println("==============================================");
  Serial.println(" ESP32-S3-1U-N8 Hardware Test (USB Serial)");
  Serial.println("==============================================");
  Serial.println("Tests:");
  Serial.println("  1) IO1 LED blink test");
  Serial.println("  2) IO48 RGB LED color test");
  Serial.println("  3) MEM heap read/write test");
  Serial.print("  4) I2C scan on IO");
  Serial.print(PIN_I2C_SDA);
  Serial.print("/IO");
  Serial.println(PIN_I2C_SCL);
  Serial.println("  5) USB CDC flood throughput test");
  Serial.println("  6) TMP102 detect + temperature read (0x48)");
  Serial.println("----------------------------------------------");
}

bool runMemTest() {
  Serial.print("[MEM] Running heap test with ");
  Serial.print(MEM_TEST_BYTES);
  Serial.println(" bytes...");

  uint8_t *buffer = (uint8_t *)malloc(MEM_TEST_BYTES);
  if (!buffer) {
    Serial.println("[MEM] Allocation failed.");
    return false;
  }

  bool ok = true;
  for (size_t i = 0; i < MEM_TEST_BYTES; ++i) {
    buffer[i] = (uint8_t)(i ^ 0xA5);
  }

  for (size_t i = 0; i < MEM_TEST_BYTES; ++i) {
    uint8_t expected = (uint8_t)(i ^ 0xA5);
    if (buffer[i] != expected) {
      Serial.print("[MEM] Mismatch at byte ");
      Serial.print(i);
      Serial.print(": expected 0x");
      if (expected < 0x10) Serial.print('0');
      Serial.print(expected, HEX);
      Serial.print(", got 0x");
      if (buffer[i] < 0x10) Serial.print('0');
      Serial.println(buffer[i], HEX);
      ok = false;
      break;
    }
  }

  free(buffer);

  Serial.print("[MEM] Heap test ");
  Serial.println(ok ? "PASSED." : "FAILED.");
  Serial.print("[MEM] Free heap: ");
  Serial.println(ESP.getFreeHeap());
  return ok;
}

void scanI2CDevices() {
  uint8_t foundCount = 0;

  Serial.print("[I2C] Scanning SDA=IO");
  Serial.print(PIN_I2C_SDA);
  Serial.print(" SCL=IO");
  Serial.print(PIN_I2C_SCL);
  Serial.println("...");

  for (uint8_t address = 1; address < 127; ++address) {
    Wire.beginTransmission(address);
    uint8_t error = Wire.endTransmission();
    if (error == 0) {
      Serial.print("[I2C] Device found at 0x");
      if (address < 0x10) Serial.print('0');
      Serial.println(address, HEX);
      ++foundCount;
    }
  }

  if (foundCount == 0) {
    Serial.println("[I2C] No I2C devices found.");
  }
}

void runCdcFloodTest() {
  static const uint8_t pattern[CDC_FLOOD_CHUNK_BYTES] = {
    0x55, 0x55, 0x55, 0x55, 0x55, 0x55, 0x55, 0x55,
    0x55, 0x55, 0x55, 0x55, 0x55, 0x55, 0x55, 0x55,
    0x55, 0x55, 0x55, 0x55, 0x55, 0x55, 0x55, 0x55,
    0x55, 0x55, 0x55, 0x55, 0x55, 0x55, 0x55, 0x55,
    0x55, 0x55, 0x55, 0x55, 0x55, 0x55, 0x55, 0x55,
    0x55, 0x55, 0x55, 0x55, 0x55, 0x55, 0x55, 0x55,
    0x55, 0x55, 0x55, 0x55, 0x55, 0x55, 0x55, 0x55,
    0x55, 0x55, 0x55, 0x55, 0x55, 0x55, 0x55, 0x55,
    0x55, 0x55, 0x55, 0x55, 0x55, 0x55, 0x55, 0x55,
    0x55, 0x55, 0x55, 0x55, 0x55, 0x55, 0x55, 0x55,
    0x55, 0x55, 0x55, 0x55, 0x55, 0x55, 0x55, 0x55,
    0x55, 0x55, 0x55, 0x55, 0x55, 0x55, 0x55, 0x55,
    0x55, 0x55, 0x55, 0x55, 0x55, 0x55, 0x55, 0x55,
    0x55, 0x55, 0x55, 0x55, 0x55, 0x55, 0x55, 0x55,
    0x55, 0x55, 0x55, 0x55, 0x55, 0x55, 0x55, 0x55,
    0x55, 0x55, 0x55, 0x55, 0x55, 0x55, 0x55, 0x55,
    0x55, 0x55, 0x55, 0x55, 0x55, 0x55, 0x55, 0x55,
    0x55, 0x55, 0x55, 0x55, 0x55, 0x55, 0x55, 0x55,
    0x55, 0x55, 0x55, 0x55, 0x55, 0x55, 0x55, 0x55,
    0x55, 0x55, 0x55, 0x55, 0x55, 0x55, 0x55, 0x55,
    0x55, 0x55, 0x55, 0x55, 0x55, 0x55, 0x55, 0x55,
    0x55, 0x55, 0x55, 0x55, 0x55, 0x55, 0x55, 0x55,
    0x55, 0x55, 0x55, 0x55, 0x55, 0x55, 0x55, 0x55,
    0x55, 0x55, 0x55, 0x55, 0x55, 0x55, 0x55, 0x55,
    0x55, 0x55, 0x55, 0x55, 0x55, 0x55, 0x55, 0x55,
    0x55, 0x55, 0x55, 0x55, 0x55, 0x55, 0x55, 0x55,
    0x55, 0x55, 0x55, 0x55, 0x55, 0x55, 0x55, 0x55,
    0x55, 0x55, 0x55, 0x55, 0x55, 0x55, 0x55, 0x55,
    0x55, 0x55, 0x55, 0x55, 0x55, 0x55, 0x55, 0x55,
    0x55, 0x55, 0x55, 0x55, 0x55, 0x55, 0x55, 0x55,
    0x55, 0x55, 0x55, 0x55, 0x55, 0x55, 0x55, 0x55
  };

  Serial.print("[CDC] Flooding USB CDC for ");
  Serial.print(CDC_FLOOD_TEST_MS);
  Serial.println(" ms...");

  uint32_t startMs = millis();
  uint32_t bytesWritten = 0;

  while ((millis() - startMs) < CDC_FLOOD_TEST_MS) {
    size_t written = Serial.write(pattern, CDC_FLOOD_CHUNK_BYTES);
    bytesWritten += written;

    if (written == 0) {
      delay(1);
    }
  }

  Serial.flush();

  uint32_t elapsedMs = millis() - startMs;
  float throughputMbps = (bytesWritten * 8.0f) / (elapsedMs / 1000.0f) / 1000000.0f;

  Serial.println();
  Serial.print("[CDC] Sent ");
  Serial.print(bytesWritten);
  Serial.print(" bytes in ");
  Serial.print(elapsedMs);
  Serial.print(" ms -> ");
  Serial.print(throughputMbps, 2);
  Serial.println(" Mbit/s");
}

void setRgb(uint8_t r, uint8_t g, uint8_t b) {
  // ESP32 Arduino core builtin for WS2812-style RGB LEDs.
  neopixelWrite(PIN_RGB, r, g, b);
}

void hsvToRgb(uint16_t hue, uint8_t sat, uint8_t val, uint8_t &r, uint8_t &g, uint8_t &b) {
  if (sat == 0) {
    r = val;
    g = val;
    b = val;
    return;
  }

  uint16_t h = hue % 360;
  uint8_t region = h / 60;
  uint16_t remainder = (h % 60) * 255 / 60;

  uint16_t p = (uint16_t)val * (255 - sat) / 255;
  uint16_t q = (uint16_t)val * (255 - ((uint16_t)sat * remainder / 255)) / 255;
  uint16_t t = (uint16_t)val * (255 - ((uint16_t)sat * (255 - remainder) / 255)) / 255;

  switch (region) {
    case 0:
      r = val; g = t; b = p;
      break;
    case 1:
      r = q; g = val; b = p;
      break;
    case 2:
      r = p; g = val; b = t;
      break;
    case 3:
      r = p; g = q; b = val;
      break;
    case 4:
      r = t; g = p; b = val;
      break;
    default:
      r = val; g = p; b = q;
      break;
  }
}

bool tmp102Detect() {
  Wire.beginTransmission(TMP102_ADDR);
  return (Wire.endTransmission() == 0);
}

bool tmp102ReadCelsius(float &tempC) {
  Wire.beginTransmission(TMP102_ADDR);
  Wire.write(TMP102_REG_TEMP);
  if (Wire.endTransmission(false) != 0) {
    return false;
  }

  if (Wire.requestFrom((int)TMP102_ADDR, 2) != 2) {
    return false;
  }

  uint8_t msb = Wire.read();
  uint8_t lsb = Wire.read();
  int16_t raw = ((int16_t)msb << 8) | lsb;

  // TMP102 temperature is in bits [15:4], signed 12-bit, 0.0625 C/LSB.
  raw >>= 4;
  if (raw & 0x0800) {
    raw |= 0xF000;
  }

  tempC = raw * 0.0625f;
  return true;
}

void setup() {
  pinMode(PIN_LED, OUTPUT);
  digitalWrite(PIN_LED, LOW);

  pinMode(PIN_RGB, OUTPUT);
  setRgb(0, 0, 0);

  Wire.begin(PIN_I2C_SDA, PIN_I2C_SCL);

  Serial.begin(115200);
  unsigned long startMs = millis();
  while (!Serial && (millis() - startMs < 5000)) {}

  printBanner();

  scanI2CDevices();

  tmp102Found = tmp102Detect();
  if (tmp102Found) {
    Serial.println("[TMP102] Found at I2C address 0x48.");
  } else {
    Serial.println("[TMP102] NOT found at 0x48. Check SDA/SCL wiring and power.");
  }

  runMemTest();
  runCdcFloodTest();

  uint32_t now = millis();
  nextLedEventMs = now;
  nextRgbEventMs = now;
  nextTempEventMs = now;

  Serial.println("Entering continuous monitor loop...");
}

void loop() {
  uint32_t now = millis();

  if ((int32_t)(now - nextLedEventMs) >= 0) {
    ledState = !ledState;
    digitalWrite(PIN_LED, ledState ? HIGH : LOW);
    nextLedEventMs = now + (ledState ? LED_ON_TIME_MS : LED_OFF_TIME_MS);
  }

  if ((int32_t)(now - nextRgbEventMs) >= 0) {
    uint8_t r = 0;
    uint8_t g = 0;
    uint8_t b = 0;
    hsvToRgb(hueDeg, 255, RGB_LED_BRIGHTNESS, r, g, b);
    setRgb(r, g, b);
    hueDeg = (hueDeg + HUE_STEP) % (HUE_MAX + 1);
    nextRgbEventMs = now + RGB_UPDATE_INTERVAL_MS;
  }

  if ((int32_t)(now - nextTempEventMs) >= 0) {
    float tC = 0.0f;
    if (tmp102Found && tmp102ReadCelsius(tC)) {
      float tF = (tC * 9.0f / 5.0f) + 32.0f;
      Serial.print("T[°C]:");
      Serial.print(tC, 2);
      Serial.print(" T[°F]: ");
      Serial.println(tF, 2);
    } else {
      Serial.println("[TMP102] Read failed.");
    }

    nextTempEventMs = now + TEMP_READ_INTERVAL_MS;
  }
}

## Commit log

2026-02-09 Add section for ESP32-S3-MINI to README
2026-02-09 First Release
    [ESP32-S3-MINI-1_UU-B_Cu.gbr, ESP32-S3-MINI-1_UU-B_Mask.gbr, ESP32-S3-MINI-1_UU-B_Paste.gbr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]
2026-02-09 Design Review
    [ESP32-S3-MINI-1_UU-B_Cu.gbr, ESP32-S3-MINI-1_UU-B_Mask.gbr, ESP32-S3-MINI-1_UU-B_Paste.gbr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]
2026-02-15 1U module release
    [BOM.xlsx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]
2026-02-15 Adjust image width for ESP32-S3-MINI-1
    Reduced image width for ESP32-S3-MINI-1 in README.
2026-02-15 reorganized folders
    [BOM.xlsx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]
2026-02-16 ESP32-S3-1 updates from 1U design
    [ESP32-S3-MINI-1_UU-B_Cu.gbr, ESP32-S3-MINI-1_UU-B_Mask.gbr, ESP32-S3-MINI-1_UU-B_Paste.gbr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]
2026-02-16 BOM update
    [BOM.xlsx, ESP32-S3-MINI-1U_UU.csv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]
2026-02-16 Silk update
    [ESP32-S3-MINI-1_UU-B_Cu.gbr, ESP32-S3-MINI-1_UU-B_Mask.gbr, ESP32-S3-MINI-1_UU-B_Paste.gbr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]
2026-02-16 Sync Update
    [ESP32-S3-MINI-1U_UU-B_Cu.gbr, ESP32-S3-MINI-1U_UU-B_Mask.gbr, ESP32-S3-MINI-1U_UU-B_Paste.gbr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]
2026-02-17 Trace cleanup
    [ESP32-S3-MINI-1U_UU-B_Cu.gbr, ESP32-S3-MINI-1U_UU-B_Mask.gbr, ESP32-S3-MINI-1U_UU-B_Paste.gbr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]
2026-02-26 Differential USB routing
    [ESP32-S3-MINI-1U_UU-B_Cu.gbr, ESP32-S3-MINI-1U_UU-B_Mask.gbr, ESP32-S3-MINI-1U_UU-B_Paste.gbr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]
2026-06-03 Update ESP32 PCB projects and generated assets
    [B2B-PH-SM4-TB__LF__SN_.stp, BMA400.step, BOM.xlsx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]
2026-06-03 Add ESP32-S3-MINI-1U Arduino folder and ignore KiCad backups
2026-06-03 Fix markdown document links and ignore KiCad lock files

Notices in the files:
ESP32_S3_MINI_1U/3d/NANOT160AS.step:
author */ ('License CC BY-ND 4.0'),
